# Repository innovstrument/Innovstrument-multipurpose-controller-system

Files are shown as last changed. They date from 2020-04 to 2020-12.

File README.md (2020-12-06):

# Innovstrument-multipurpose-controller-system

## 第一节 综述 Comprehensive Presentation

多用途控制系统，旨在提供一套除传统PLC解决方案之外，基于系统单芯片（SoC）平台的解决方案。它可以提供的软、硬件功能包括但不限于以下几点：

·实时的视频摄录和上传。

·基于网络、面向使用者的寻址/解析服务。该服务同时附带了基于LDAP的用户权限控制。

·

·

## 第二节 硬件部分 Hardware Section

### 主机板 Motherboard

基于Intel Apollo Lake平台，提供的扩展性能如下：

·显示：Display Port

·外设输出： 4* USB 3.0 

·网络：2* Intel i211

·

·

#### 待解决问题

·摄像头传感器：OmniVision OV5695 ，需要ASL CODE。

#### 第二版需要的更新

·剩余的4条PCIe通道从SFF-8612/8643口引出

·提供一个MIPI-DSI输出端子。

·板载存储从eMMC转换为microSD插槽

·显示接口变成mini DisplayPort或者使用USB Type-C连接器

·

### 背板/提升板 Backplane/Riser Board

#### 背板

预留4通道的PCI Express输入（SFF-8643/8612）

方案1：桥片使用PLX PEX8614 芯片，输出接口为SFF-8639。通道4，2，1，1.

方案2：桥片使用PLX PEX8608 芯片，输出接口为SFF-8639。通道1，1，1，1.

方案3：桥片使用PLX PEX8606 芯片，输入为两个PCIe通道。输出接口为SFF-8639，通道1，1，1，1.

#### 提升板

面积120* 120 毫米，输入为SFF-8643或8612接口，输出一个SFF-8639端口接U.2设备或者通过转接卡接M.2设备。

### 外接设备 Peripherals

目录：

1. 支持PoE的以太网卡

2. 以太网卡

3. 附属电池

4. 

### 模拟-数字信号转换控制模块 Analog-Digital Signal Convert and Control Module

·芯片 Analog Devices BF706: https://www.analog.com/cn/products/adsp-bf706.html#product-overview

·子通道控制 Analog Devices AD 5674：https://www.analog.com/media/en/technical-documentation/data-sheets/AD5674-5674R-5679-5679R.pdf

·提供的模拟输入：16路电压型 16路电流型

·提供的模拟输出：8路 10mA，0-5V.

·采样精度：10 bit.

图纸位于目录/master/Hardware/Analog-Digital%20Convert%20System下，编辑需要使用Altium Designer。

### 测试平台：

//

## 第三节 软件部分 Software Section

### 既有软件编程：可编程逻辑控制器程序 Existing Software Programming: PLC Program

Link: Programmable Logic System/Logic/消毒机(1).zap15_1

若需要编辑程序,需要西门子SIMATIC TIA 15.1 以上的版本访问

内网下载链接:(粤网 源创)

V 15.1: http://192.168.2.54/Software/Siemens/Simatic/0_TIA_Portal_v15.1_SitePack/

V 16.0: http://192.168.2.54/Software/Siemens/Simatic/TIA_Portal_V16/

## 第四节 其它注意事项 Misc.

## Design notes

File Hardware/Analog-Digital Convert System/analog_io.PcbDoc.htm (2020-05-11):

Reporting Options

# File in Previous Format

Date | : | 2020/5/8
Time | : | 16:24:50
Filename | : | C:\Users\chang\Downloads\analog_io\analog_io.PcbDoc

Version | Warning
Release 12 | CAUTION - Air Gap Width previously controlled by Clearance rule is now controlled by Polygon Connect Style rule's newly introduced Air Gap Width (set to default value). Suggest reviewing each Polygon Connect Style rule's Air Gap Width attribute for correctness.
Release 13 | CAUTION - Silkscreen Over Component Pads Rules are converted to Silk To Solder Mask Clearance Rules. Suggest examining rule scopes for accuracy.

This file was generated by an earlier version of the software

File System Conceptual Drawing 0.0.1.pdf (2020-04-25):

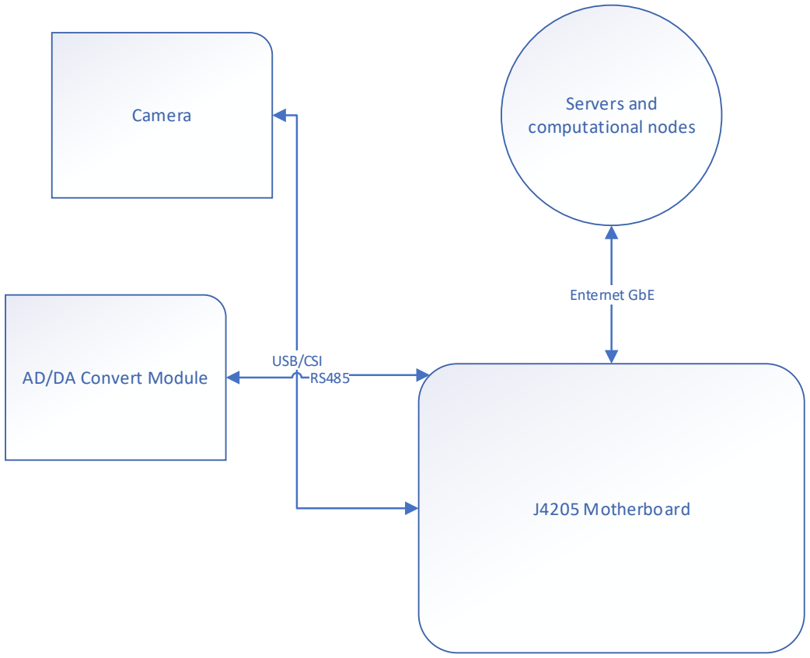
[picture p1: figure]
J4205 Motherboard; Servers and computational nodes; Enternet GbE; Camera; AD/DA Convert Module; USB/CSI RS485

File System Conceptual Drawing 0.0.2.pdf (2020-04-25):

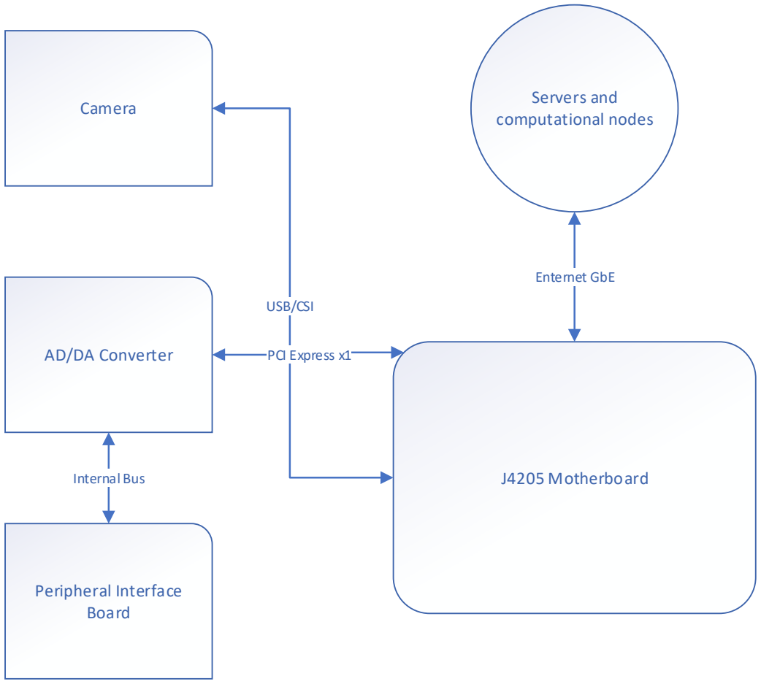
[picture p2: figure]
J4205 Motherboard; Servers and computational nodes; Enternet GbE; Camera; AD/DA Converter; USB/CSI; PCI Express x1; Peripheral Interface Board; Internal Bus

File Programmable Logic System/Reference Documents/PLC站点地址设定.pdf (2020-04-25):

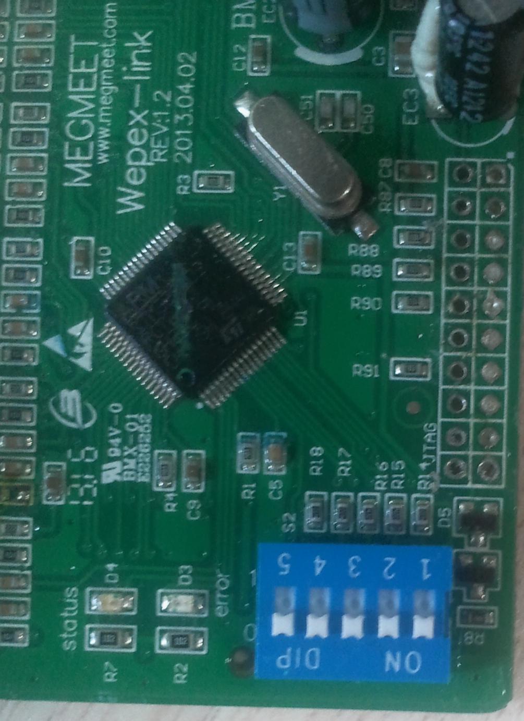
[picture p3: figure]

PLC 站点地址：1

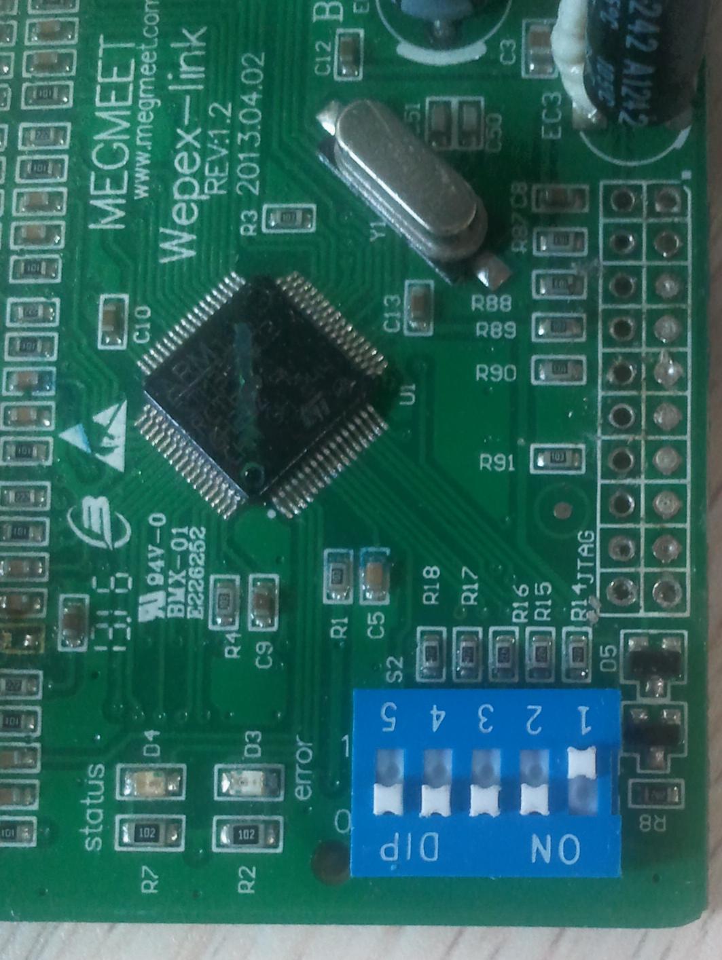
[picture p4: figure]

PLC 站点地址：2

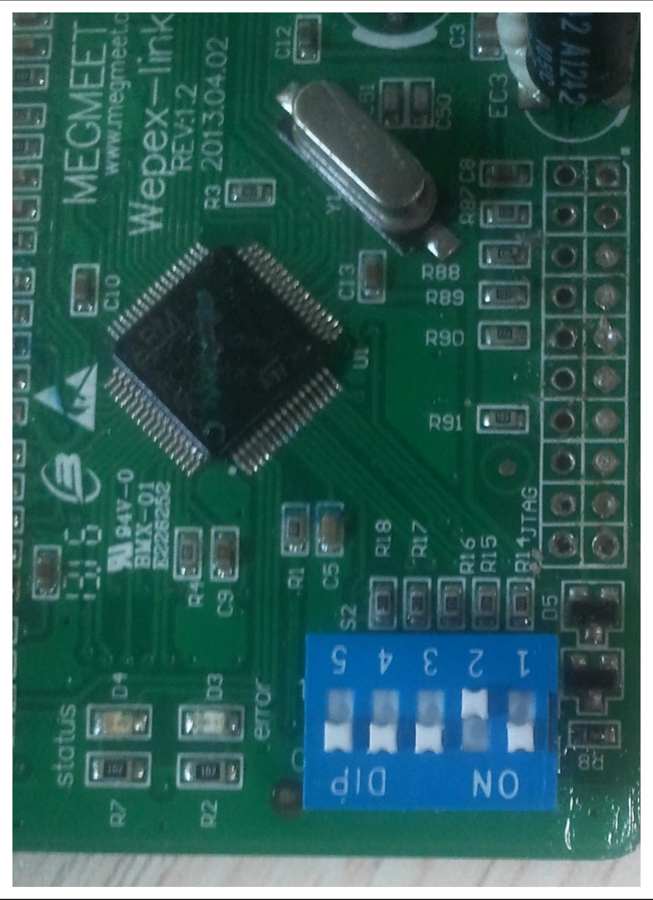
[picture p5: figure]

PLC 站点地址：3

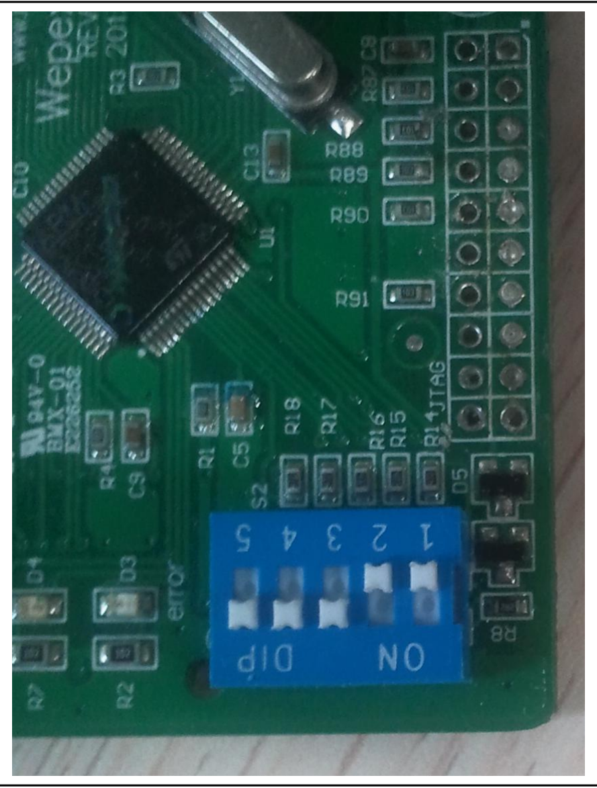
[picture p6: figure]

PLC 站点地址：4

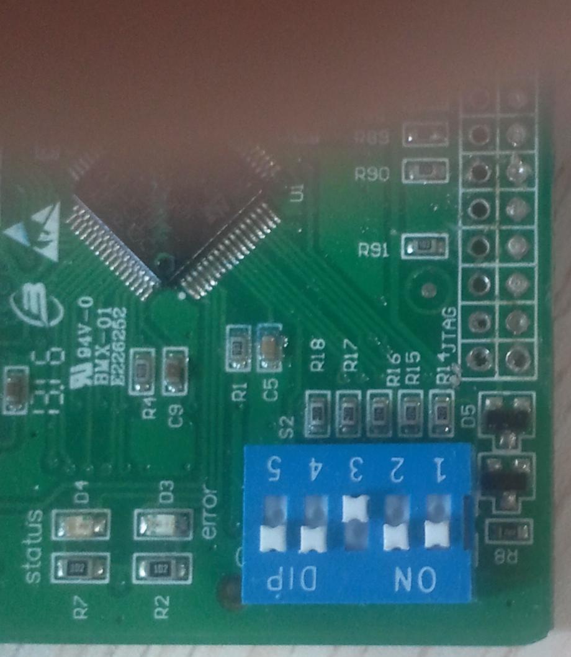
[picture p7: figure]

PLC 站点地址：5

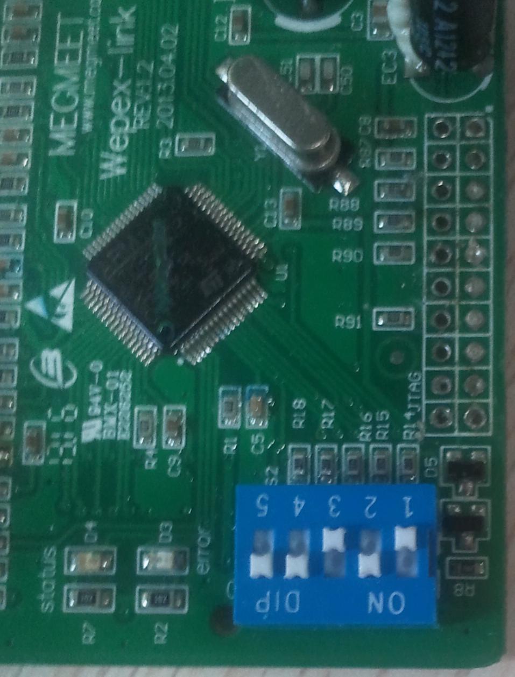
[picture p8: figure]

PLC 站点地址：6

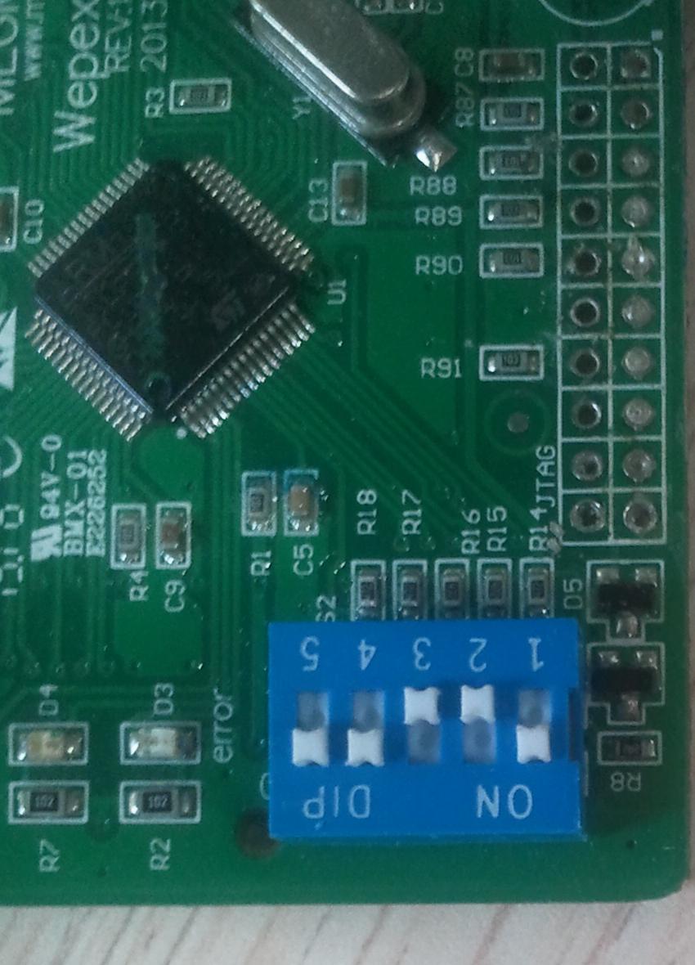
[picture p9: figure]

PLC 站点地址：7

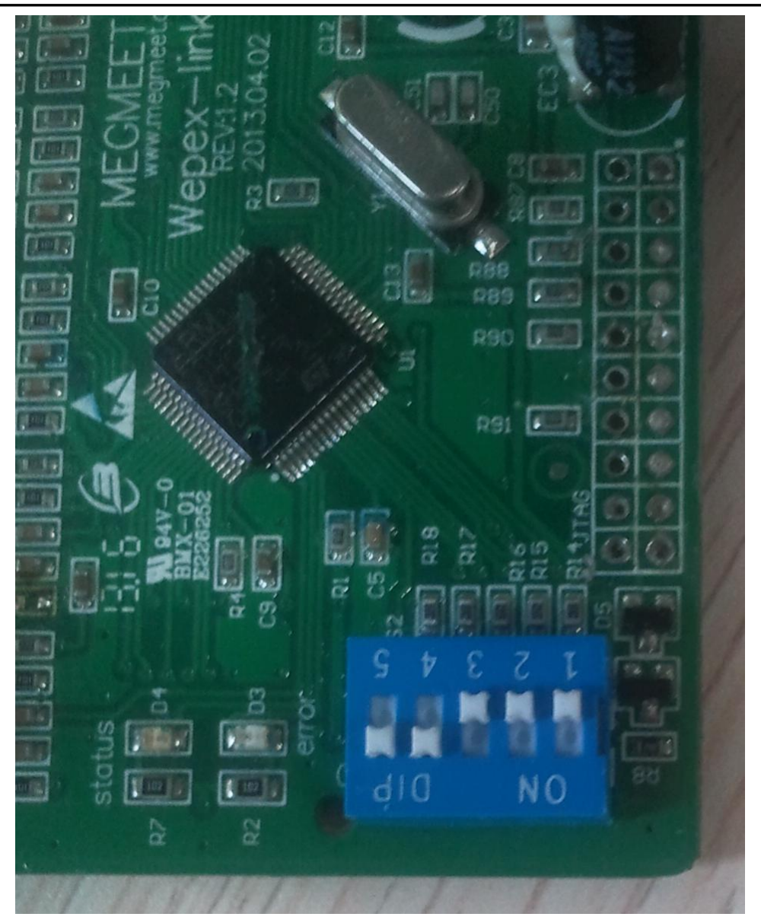
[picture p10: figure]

PLC 站点地址：8

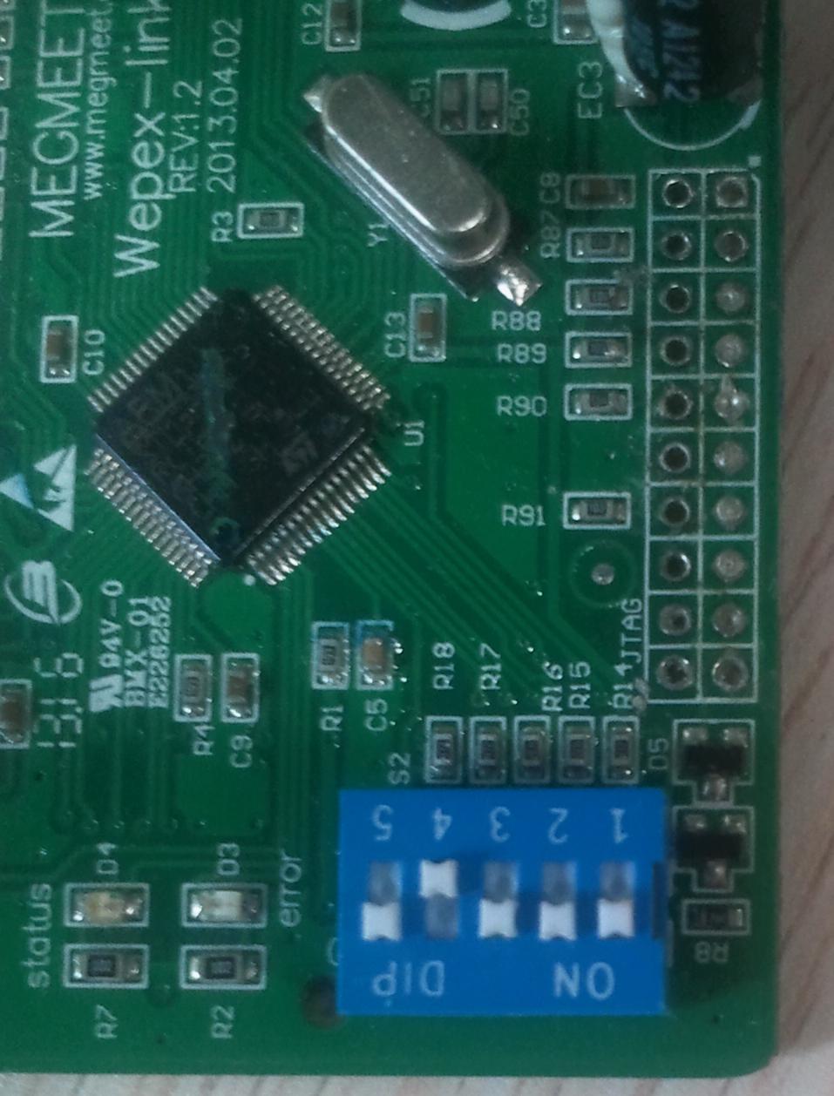
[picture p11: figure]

PLC 站点地址：9

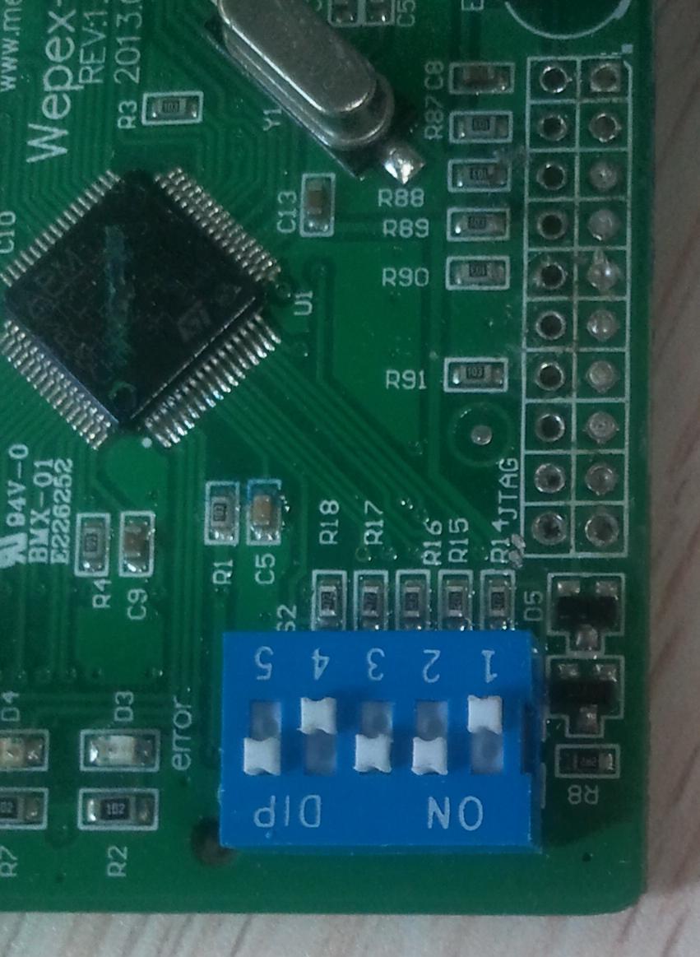
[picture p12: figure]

## PLC 站点地址：10

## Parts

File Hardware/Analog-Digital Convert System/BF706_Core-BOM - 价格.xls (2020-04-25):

Comment | Description | Designator | Footprint | LibRef | Quantity | 单价 | 总价
 | Tant Cap | C100, C101, C104, C105 | C1206T | Cap Pol2 | 4 |  | 0 | 电容的容量大小是多少？
2.2uF | Capacitor | C102, C103 | C0603 | Cap | 2 | 0.11 | 0.22
100nF | Capacitor | C106, C107, C108, C109, C110, C111, C112, C113, C114, C115, C116, C117, C118, C119, C120, C300 | C0603 | Cap | 16 | 0.043 | 0.688
18pF | Capacitor | C200, C201 | C0603 | Cap | 2 | 0.11 | 0.22
MINI-PCIE(DNP) |  | CN | PCI-E MALE | MINI-PCIE | 1 |  | 0
LED GREEN | LED GREEN | D100 | LED0603 | LED0 | 1 | 0.097 | 0.097
LED RED | LED RED | D200 | LED0603 | LED0 | 1 | 0.097 | 0.097
0512811094 | Header, 10-Pin | JTAG | MOLEX-FPC-0.5-10 | Header 10 | 1 | 0.49 | 0.49
SRN3015-2R2M | Resistor | L100, L101 | SRN3015 | Res1 | 2 | 3.59 | 7.18
10k | Resistor | R100, R200, R202, R205, R207, R208, R209, R210, R300, R301, R302, R303, R304 | R0603 | Res1 | 13 | 0.022 | 0.286
12k | Resistor | R101, R104 | R0603 | Res1 | 2 | 0.019 | 0.038
1k |  | R102 | R0603 | Res1 | 1 | 0.028 | 0.028
53.6k | Resistor | R103 | R0603 | Res1 | 1 | 0.011 | 0.011
330 |  | R201 | R0603 | Res1 | 1 | 0.02 | 0.02
DNP | Resistor | R203, R204 | R0603 | Res1 | 2 |  | 0
0R | Resistor | R206 | R0603 | Res1 | 1 | 0.009 | 0.009
ADSP-BF706BCPZ-4 |  | U100 | ADSP-BF706 | ADSP-BF706 | 1 | 137.4 | 137.4
RT8059 |  | U101, U102 | APS1006 | RT8059 | 2 | 0.67 | 1.34
ASE-24.000MHZ-LC-T | 24MHz XTAL OSC | U200 | XTAL-25M-SMD | XTAL-25M | 1 | 12.5 | 12.5
MAX811TEUS+T |  | U201 | sot143 | MAX811 | 1 | 18.4 | 18.4
W25Q32JVSSIQ |  | U300 | M25P80 | M25P16 | 1 | 2.22 | 2.22
ABM3C-25.000MHZ-D4Y-T | 25MHz XTAL | X200 | XTAL5032 | XTAL-25M-SMD | 1 | 6.15 | 6.15
 |  |  |  |  |  |  | 187.394

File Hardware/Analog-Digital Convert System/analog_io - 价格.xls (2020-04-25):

Comment | Description | Designator | Footprint | LibRef | Quantity | 单价 | 总价
1uF | Capacitor | C1, C2, C3, C5, C7, C9, C25, C26, C27, C28, C29, C30, C31, C32, C33, C34, C35, C36, C37, C38, C39, C40 | C0603 | Cap | 22 | 0.063 | 1.386
100nF | GRM155R71C104KA88J | C4, C6, C8, C10, C12, C14, C16, C18, C44, C46 | C0603 | Cap | 10 | 0.043 | 0.43
10uF | Capacitor | C11, C13, C15, C17, C45 | C1206N | Cap | 5 | 0.25 | 1.25
4.7uF | Capacitor | C19, C21, C22, C24, C41, C43 | TANT_B | Cap | 6 |  | 0 | 封装不清楚，是钽电容吗？具体封装是什么？
4.7uF | Capacitor | C20, C23, C42 | C0603 | Cap | 3 | 0.25 | 0.75
Phoenix Contact 1843156 | Header, 10-Pin, Dual row | CN1, CN2, CN3 | PHOENIX1843156 | Header 10X2 | 3 | 99 | 297
Header 24 | Header, 24-Pin | CN300 | FPC-0.5-24 | Header 24 | 1 | 0.58 | 0.58
LED0 | Typical INFRARED GaAs LED | D1, D2, D3 | LED0603 | LED0 | 3 | 0.097 | 0.291
10R | Resistor | R1, R2, R3, R4, R5, R6, R7, R8, R9, R10, R11, R12, R13, R14, R15, R16 | R0603 | Res1 | 16 | 0.017 | 0.272
2.2k | Resistor | R17, R18, R23 | R0603 | Res1 | 3 | 0.015 | 0.045
YC164-33R |  | R19, R22 | YC164 | YC164 | 2 | 0.07 | 0.14
33R | Resistor | R20, R21 | R0603 | Res1 | 2 | 0.037 | 0.074
SMAJ10CA |  | TVS1, TVS2, TVS3, TVS4, TVS5, TVS6, TVS7, TVS8, TVS9, TVS10, TVS11, TVS12, TVS13, TVS14, TVS15, TVS16 | SMA | DIODE | 16 | 0.34 | 5.44
AD4111 |  | U1, U2 | AD7119 | AD4111 | 2 | 118.4 | 236.8
AMS1117 |  | U6 | SOT223 | AMS1117-5V | 1 | 0.7 | 0.7
AMS1117 |  | U3, U4 | SOT223 | AMS1117-3.3V | 2 | 0.7 | 1.4
AD5674 |  | U5 | PNI-MAGI2C | AD5674 | 1 | 140 | 140
 |  |  |  |  |  |  | 686.558

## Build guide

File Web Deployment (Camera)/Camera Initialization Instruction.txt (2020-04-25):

Environment initialization Test:
# Set 
# List Camera Devices
ffmpeg -list_devices true -f dshow -i dummy
ffplay -f dshow -i video="Integrated Webcam" out2.mp4
# Activate HLS Steaming
ffmpeg -y -rtbufsize 1024M -f dshow -i video="Integrated Webcam" -vcodec libx264 ¨Cthreads 2 -f hls -hls_list_size 0 -hls_wrap 10 -hls_time 10 "C:\Web Deployment\wwwroot\Webcam\Buffer\Cam01\C1.m3u8"

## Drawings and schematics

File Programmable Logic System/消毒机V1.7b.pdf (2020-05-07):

| | | | 2020/3/13 | ‎深圳粤网节能技术服务有限公司 ‎消毒机控制系统 | ‎广州洁科不锈钢设备 ‎有限公司 | ‎封页 | = COVER
| | | ‎校对 | ADMIN | | | | +
| | | ‎审核 | | | | | GB_tpl001 | ‎页数
‎修改 | ‎日期 | ‎姓名 | ‎原始项目 | | ‎替换 | ‎替换人 | | | | ‎页
0 | 6 | 7
3 | 8 | 9

## =SCH+P7_PLC/1

# ‎深圳粤网节能技术服务有限公司

# ‎消毒机控制系统电气原理图

# ‎工程编号XXX-YYY-ZZZ

# ‎______年___月

# ‎施工图

X1

X1

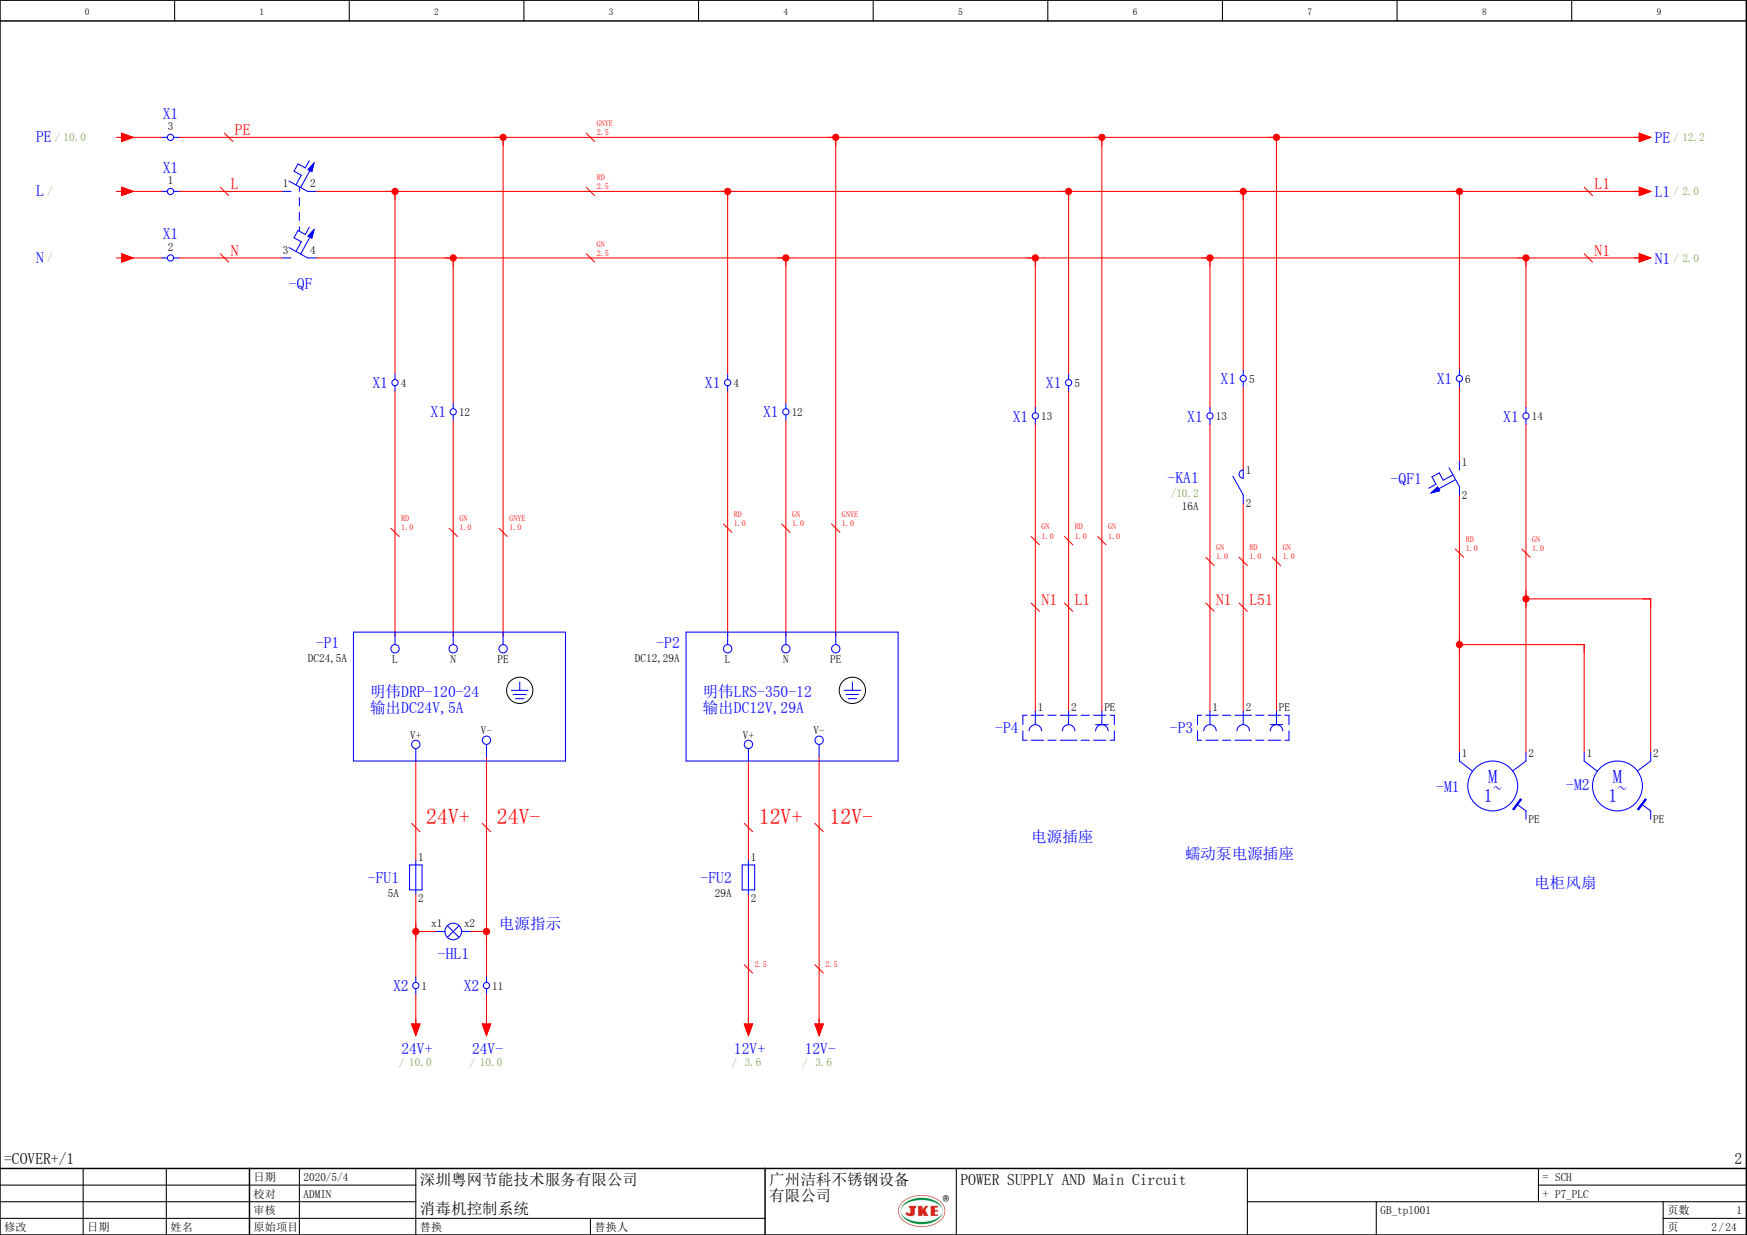
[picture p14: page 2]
=COVER+/1; SCH; P7_PLC; ‎广州洁科不锈钢设备; ‎电柜风扇; ‎明伟DRP-120-24 ‎输出DC24V,5A; ‎电源指示; ‎蠕动泵电源插座; ‎电源插座; ‎明伟LRS-350-12 ‎输出DC12V,29A; GNYE

POWER SUPPLY AND Main Circuit

24V+

-KM1

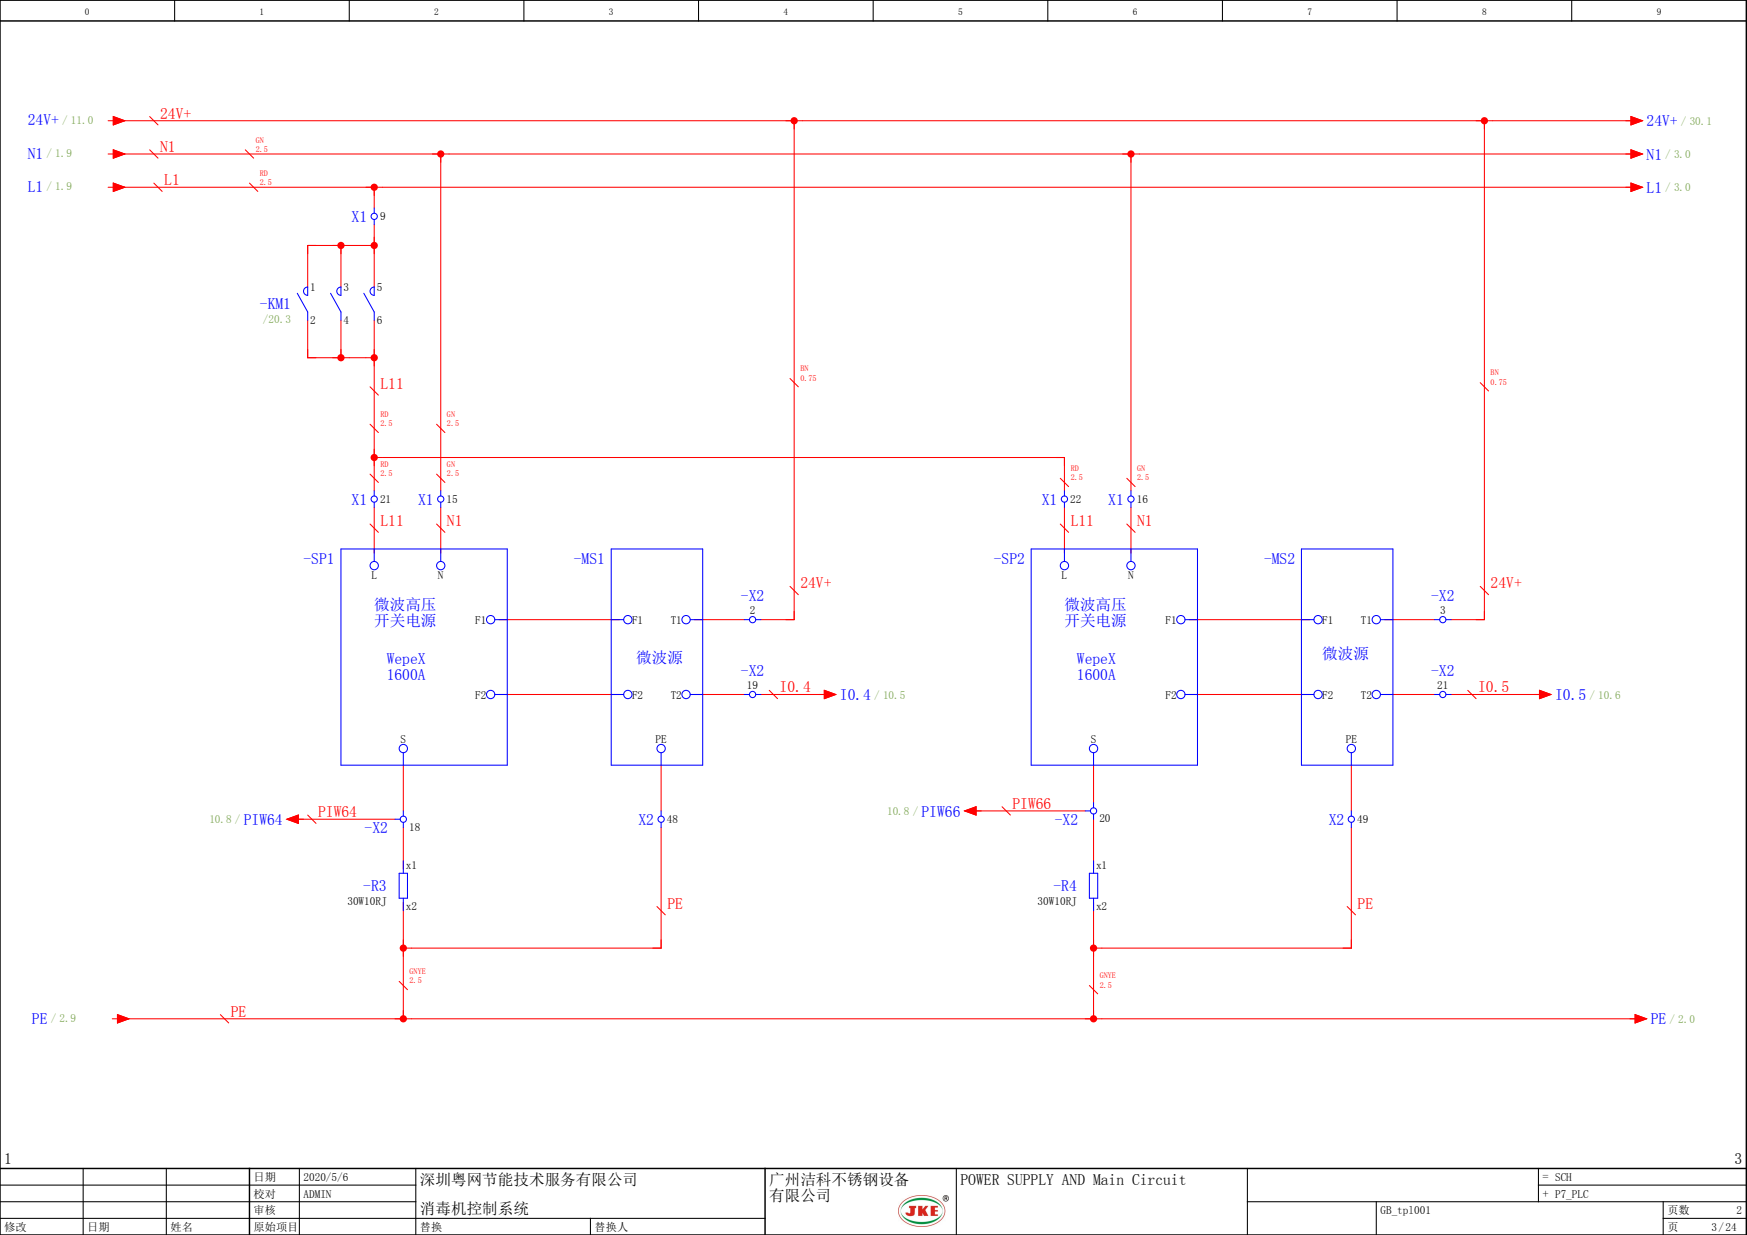
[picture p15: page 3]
SCH; P7_PLC; ‎广州洁科不锈钢设备; WepeX 1600A; ‎微波高压 ‎开关电源; ‎微波源; PIW66 PIW64; GNYE; 10.8 / PIW64; 10.8 / PIW66

POWER SUPPLY AND Main Circuit

L1

N1

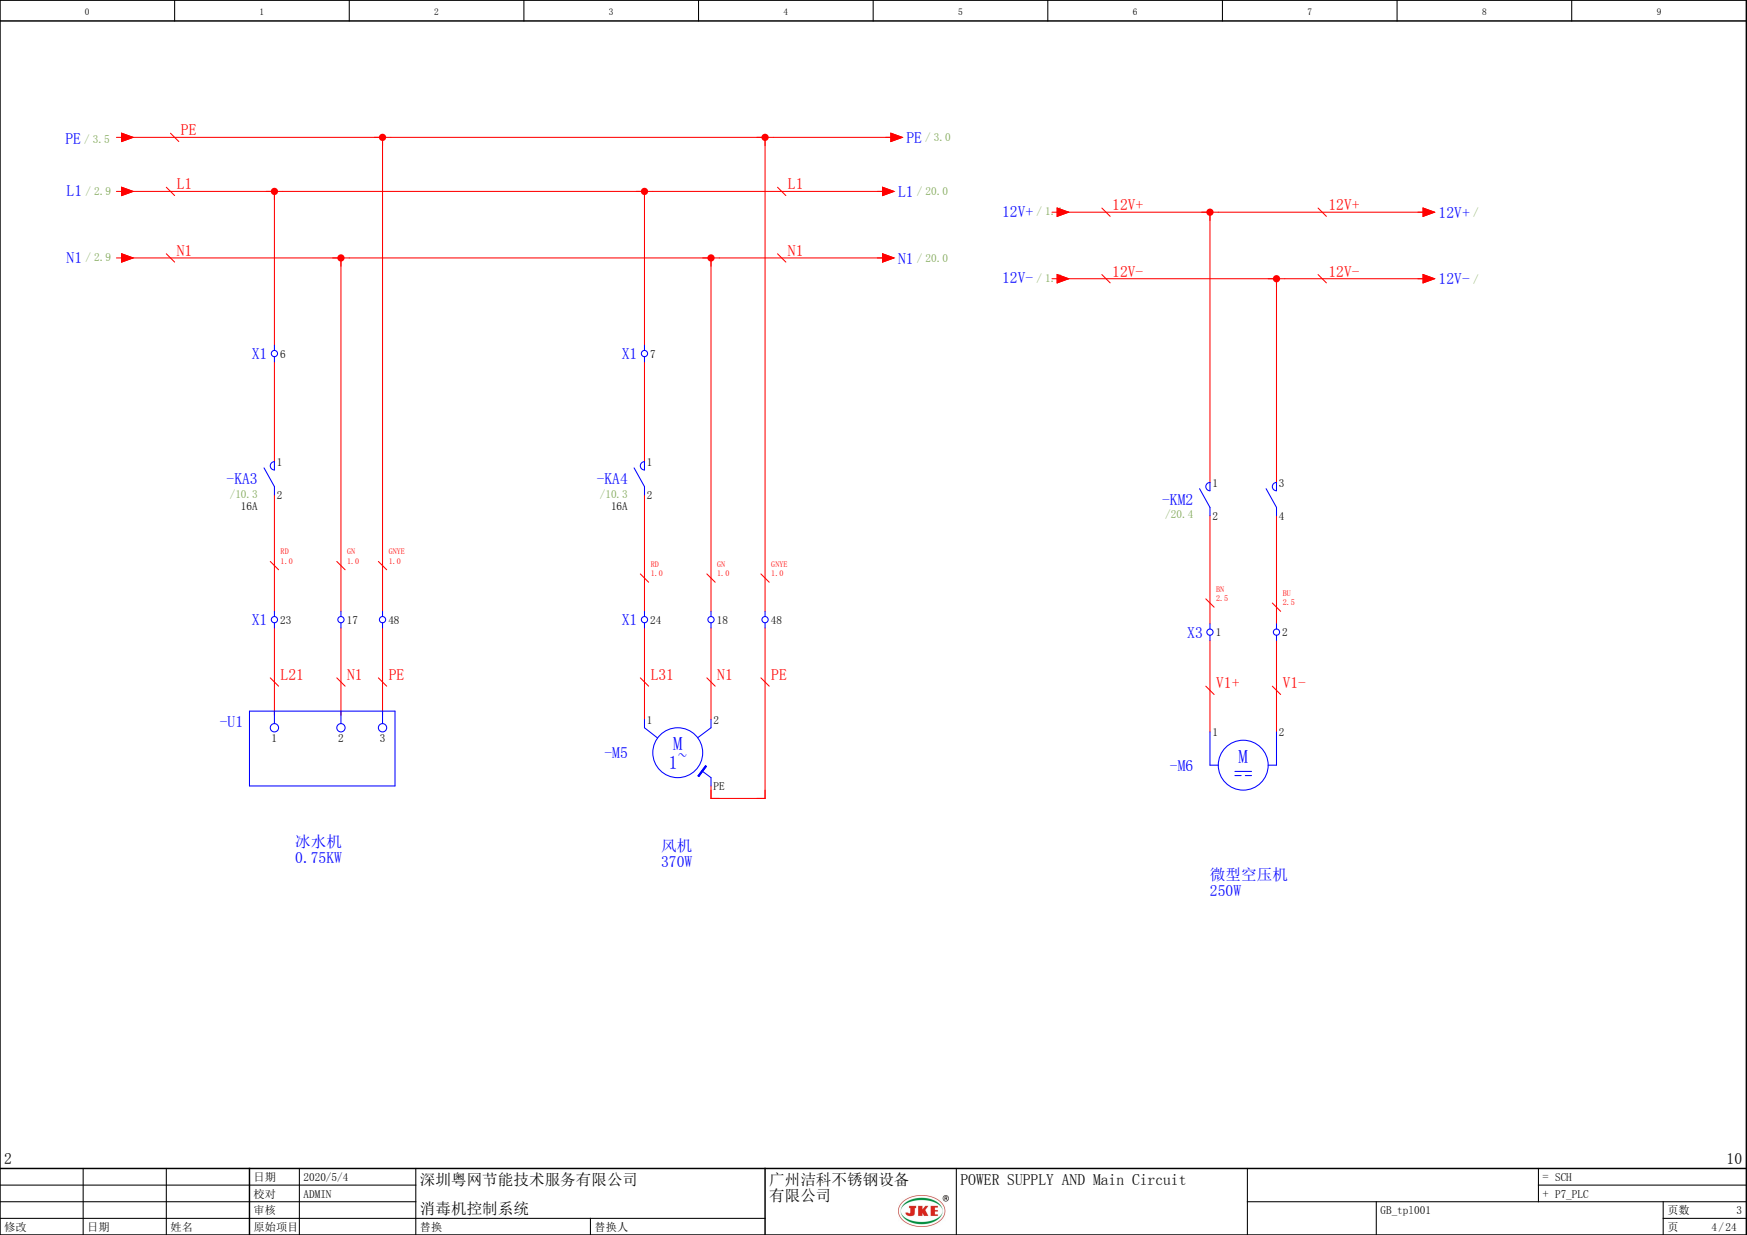
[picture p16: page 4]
SCH; P7_PLC; ‎广州洁科不锈钢设备; ‎冰水机 0.75KW; ‎微型空压机 250W; GNYE

POWER SUPPLY AND Main Circuit

24V+

24V-

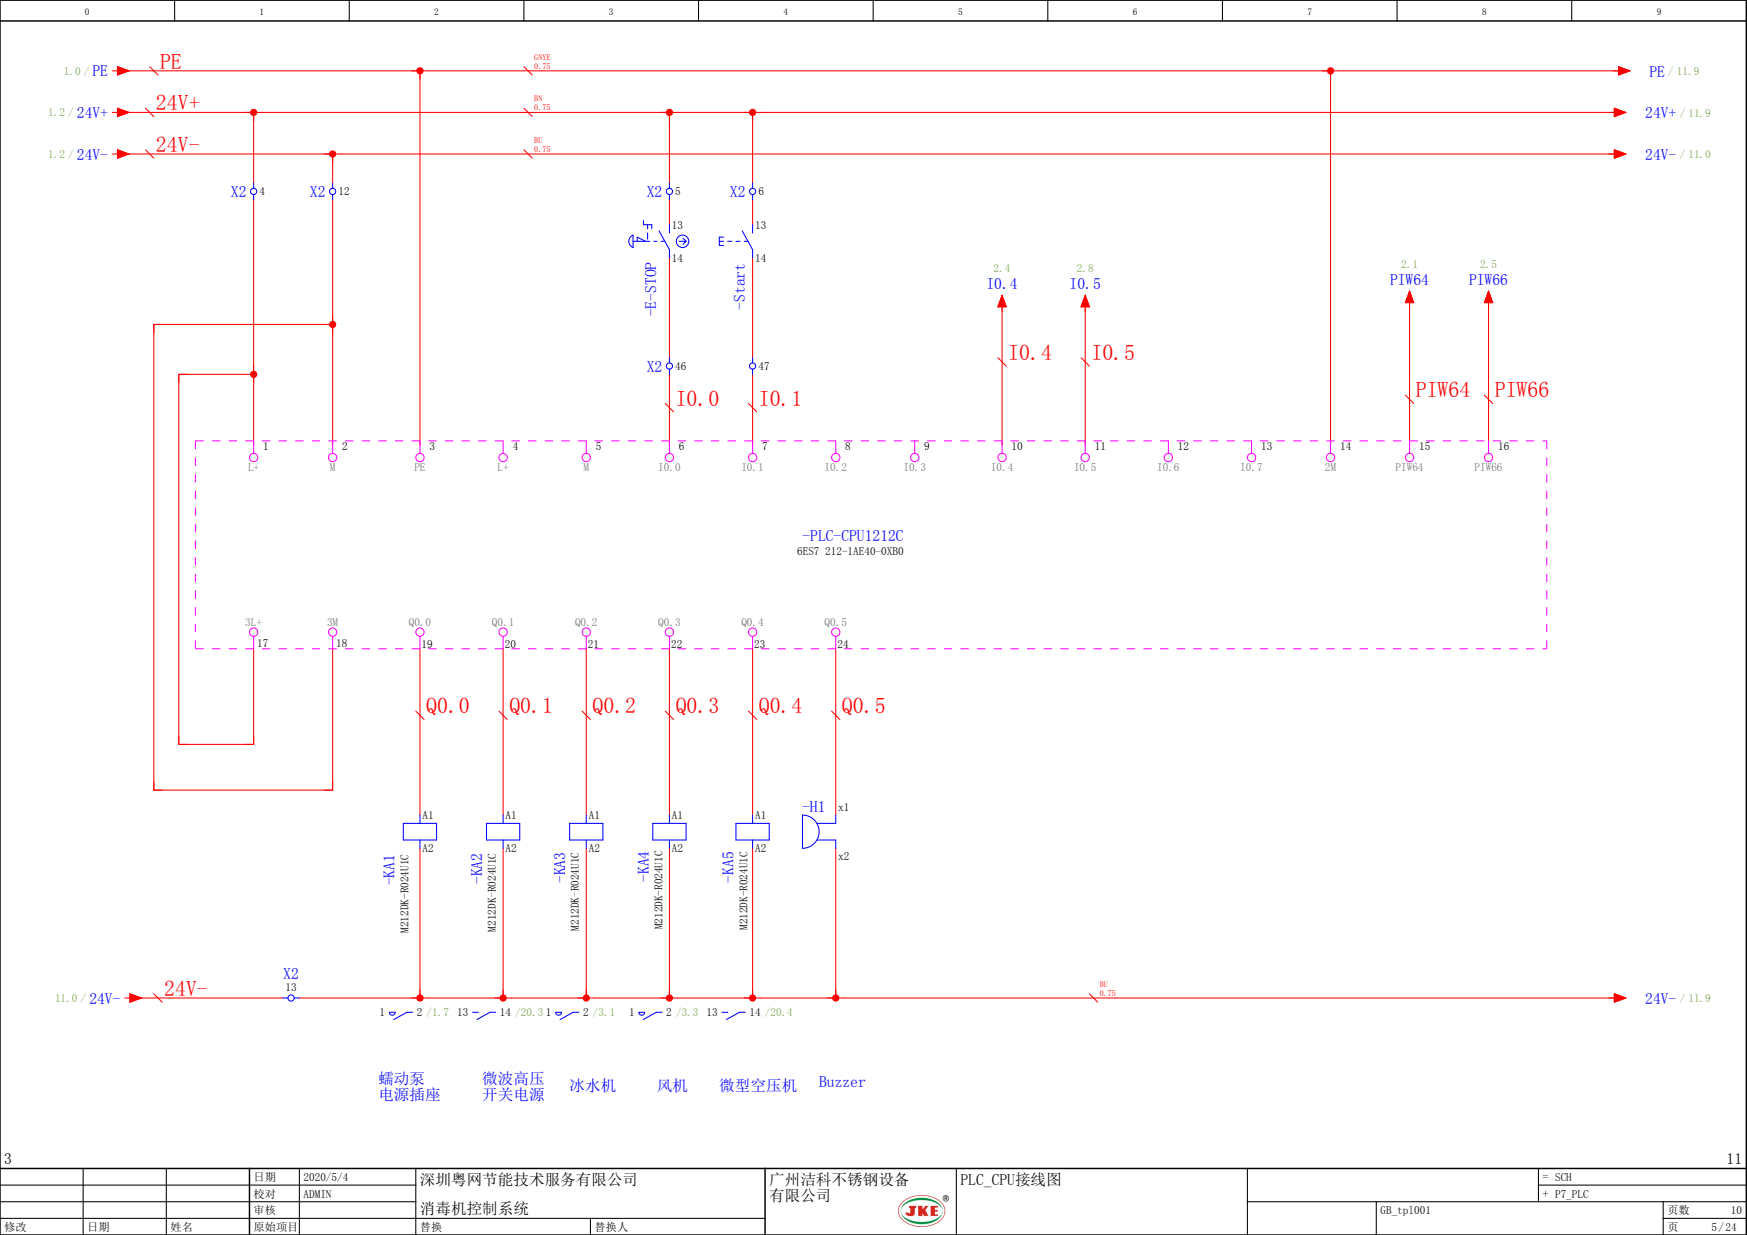
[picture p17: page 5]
SCH; P7_PLC; ‎PLC_CPU接线图; ‎广州洁科不锈钢设备; ‎蠕动泵 ‎电源插座; ‎微波高压; ‎开关电源; ‎冰水机; ‎微型空压机; Buzzer; -PLC-CPU1212C; PIW64; PIW66; -E-STOP; -Start; GNYE

24V+

24V-

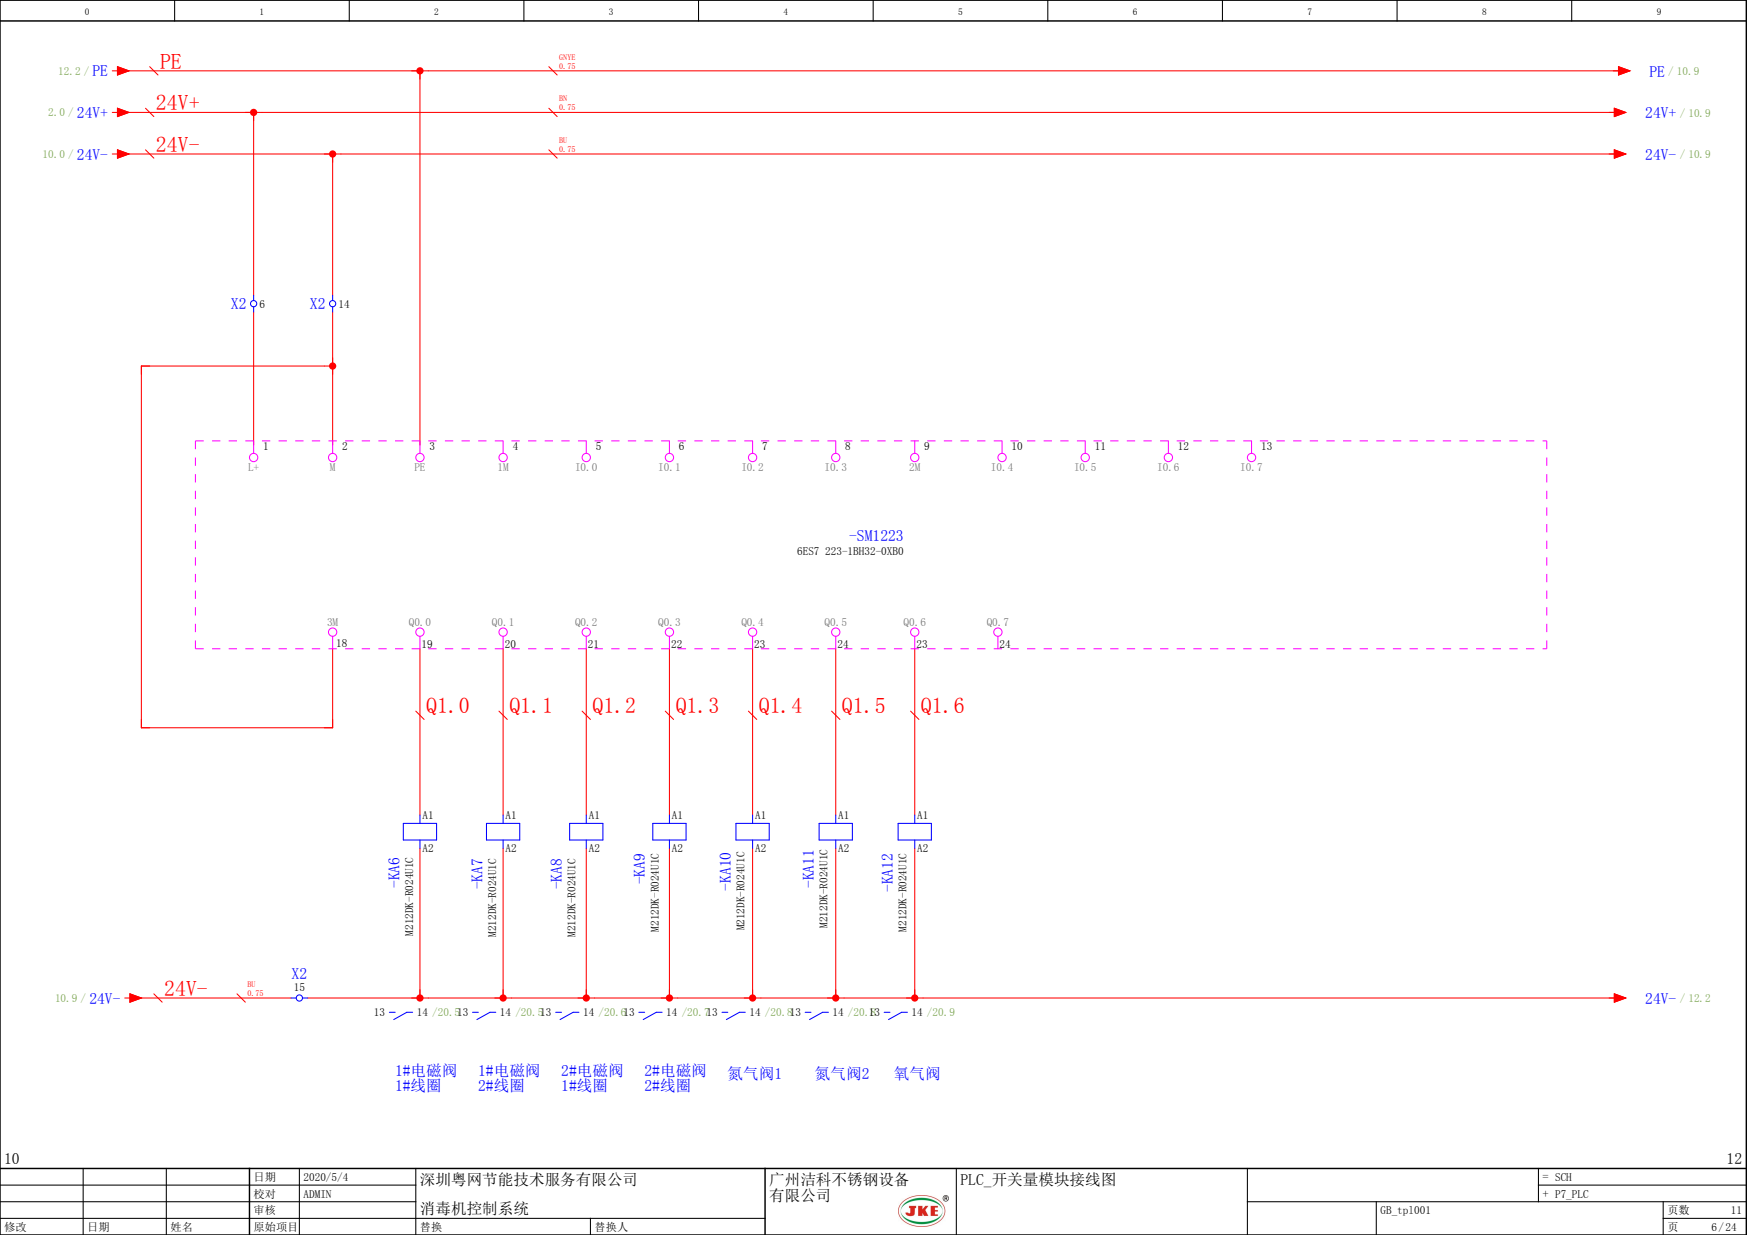
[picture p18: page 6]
SCH; P7_PLC; ‎PLC_开关量模块接线图; ‎广州洁科不锈钢设备; ‎1#电磁阀 ‎1#线圈; ‎1#电磁阀 ‎2#线圈; ‎2#电磁阀 ‎1#线圈; ‎2#电磁阀; ‎氮气阀1; ‎氮气阀2; ‎氧气阀; GNYE

24V+

24V-

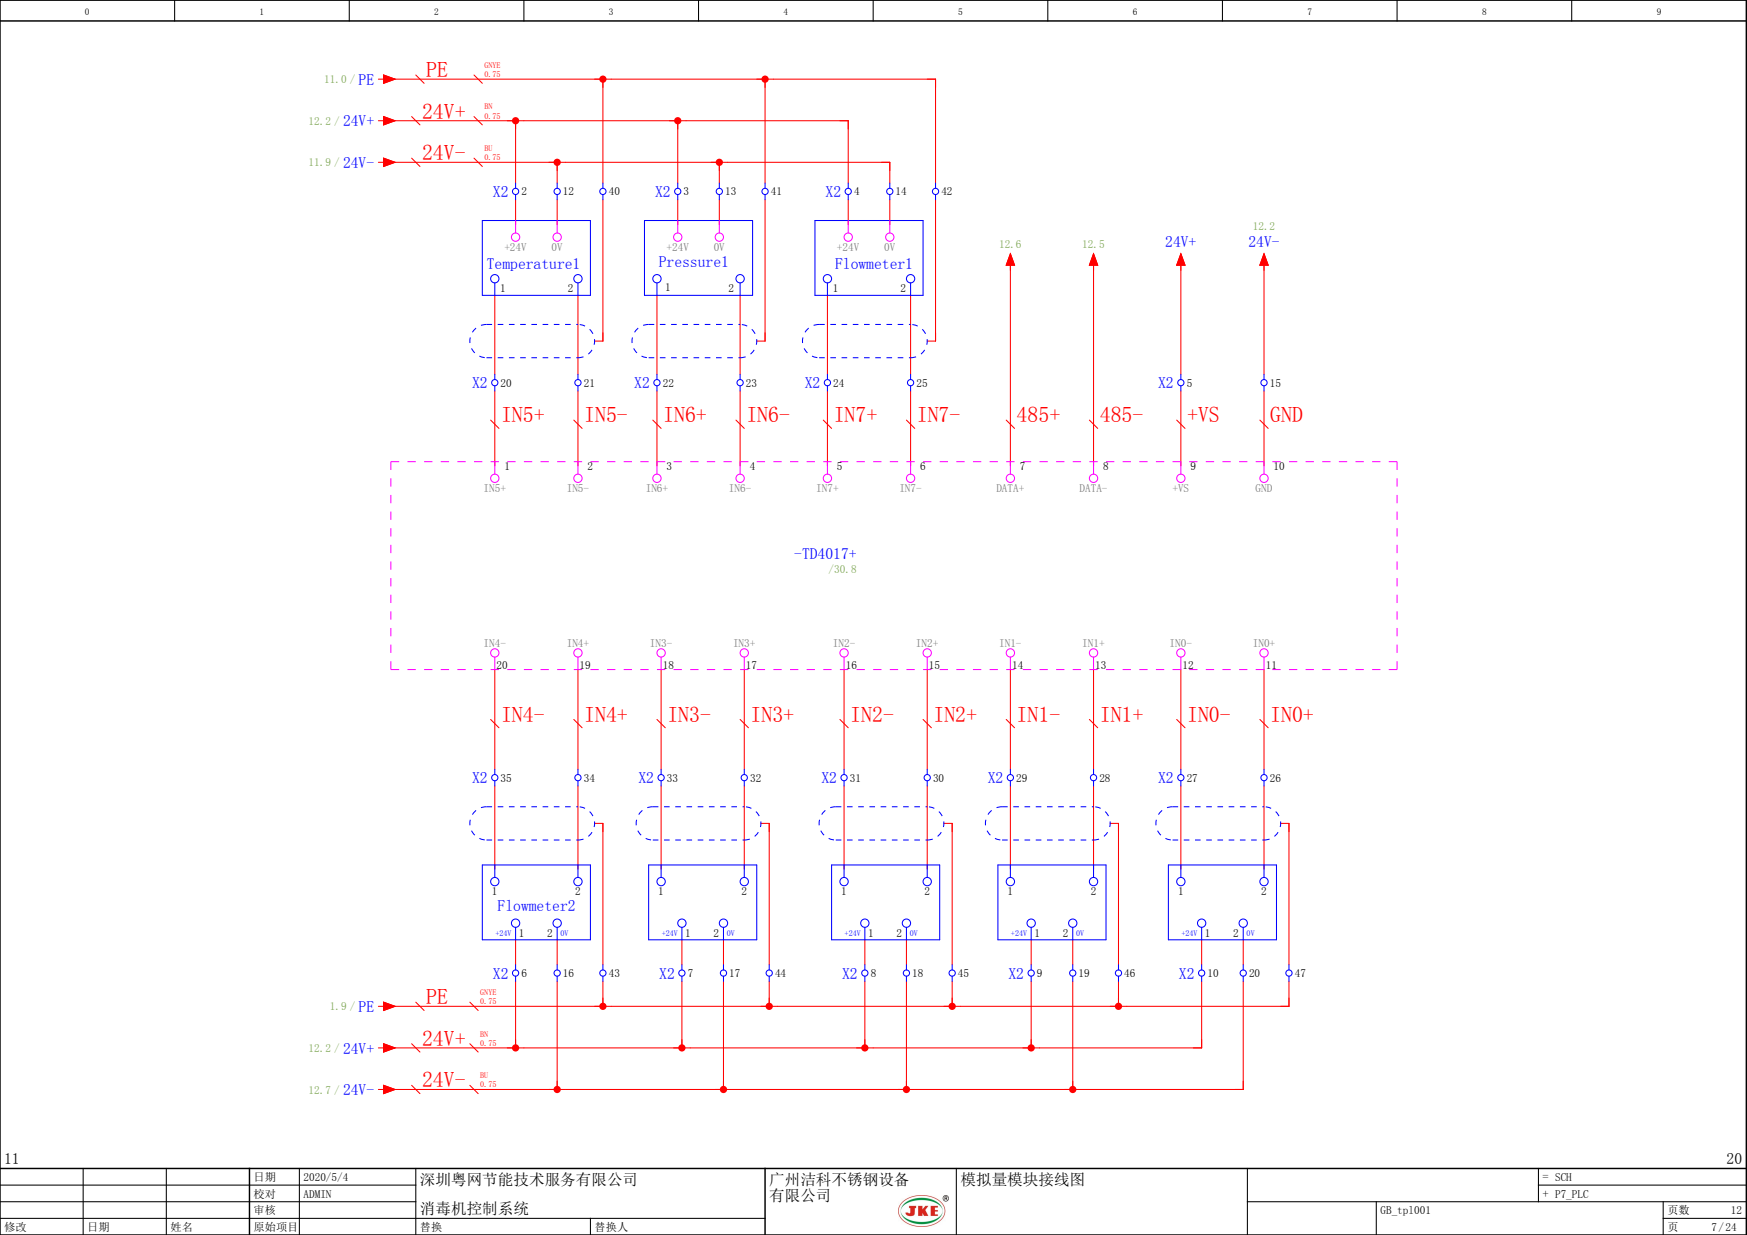
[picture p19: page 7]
SCH; P7_PLC; ‎模拟量模块接线图; ‎广州洁科不锈钢设备; Temperature1; Pressure1; Flowmeter2; Flowmeter1; DATA+; DATA-; GND; GNYE

L1

X1

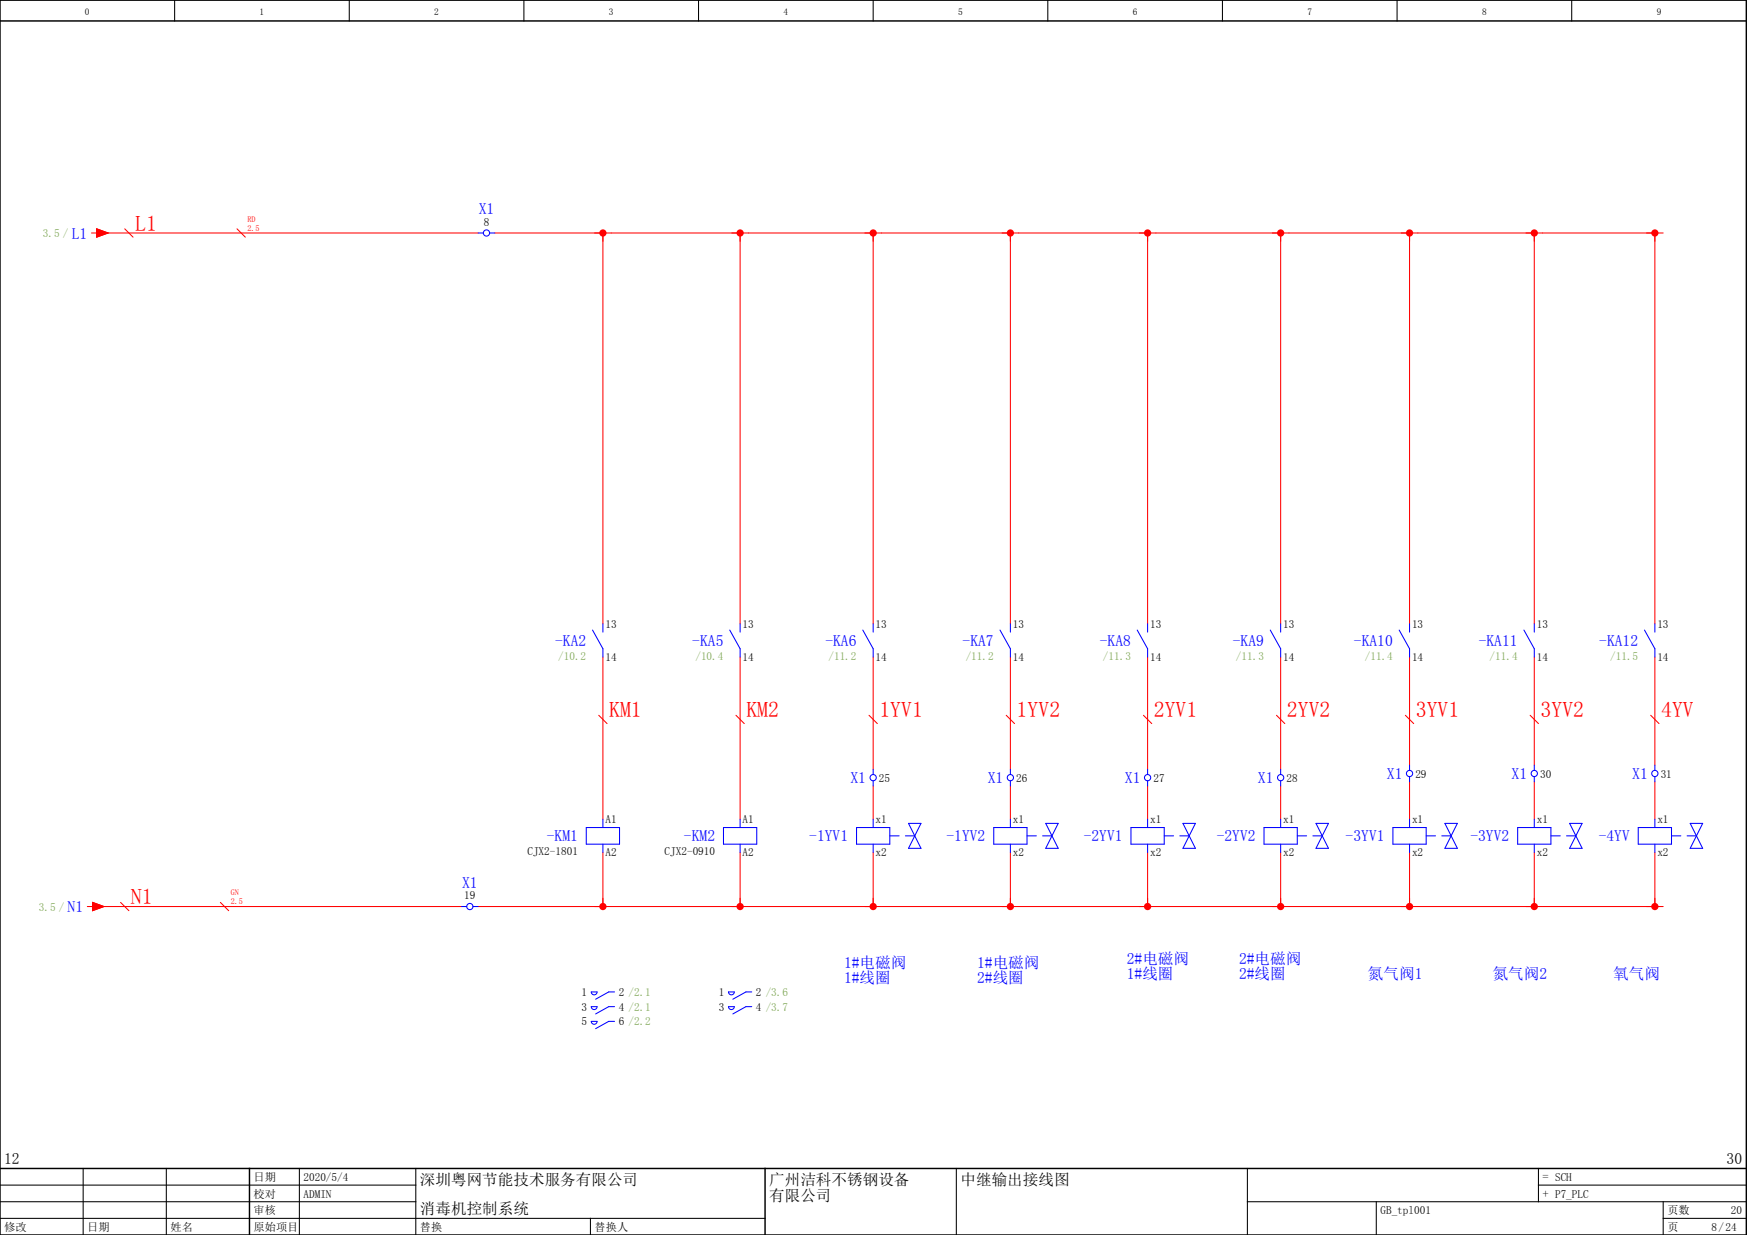
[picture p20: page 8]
SCH; P7_PLC; ‎中继输出接线图; ‎广州洁科不锈钢设备; ‎1#电磁阀 ‎1#线圈; ‎1#电磁阀 ‎2#线圈; ‎2#电磁阀 ‎1#线圈; ‎2#电磁阀; ‎氮气阀1; ‎氮气阀2; ‎氧气阀; CJX2-1801; CJX2-0910

24V+

24V-

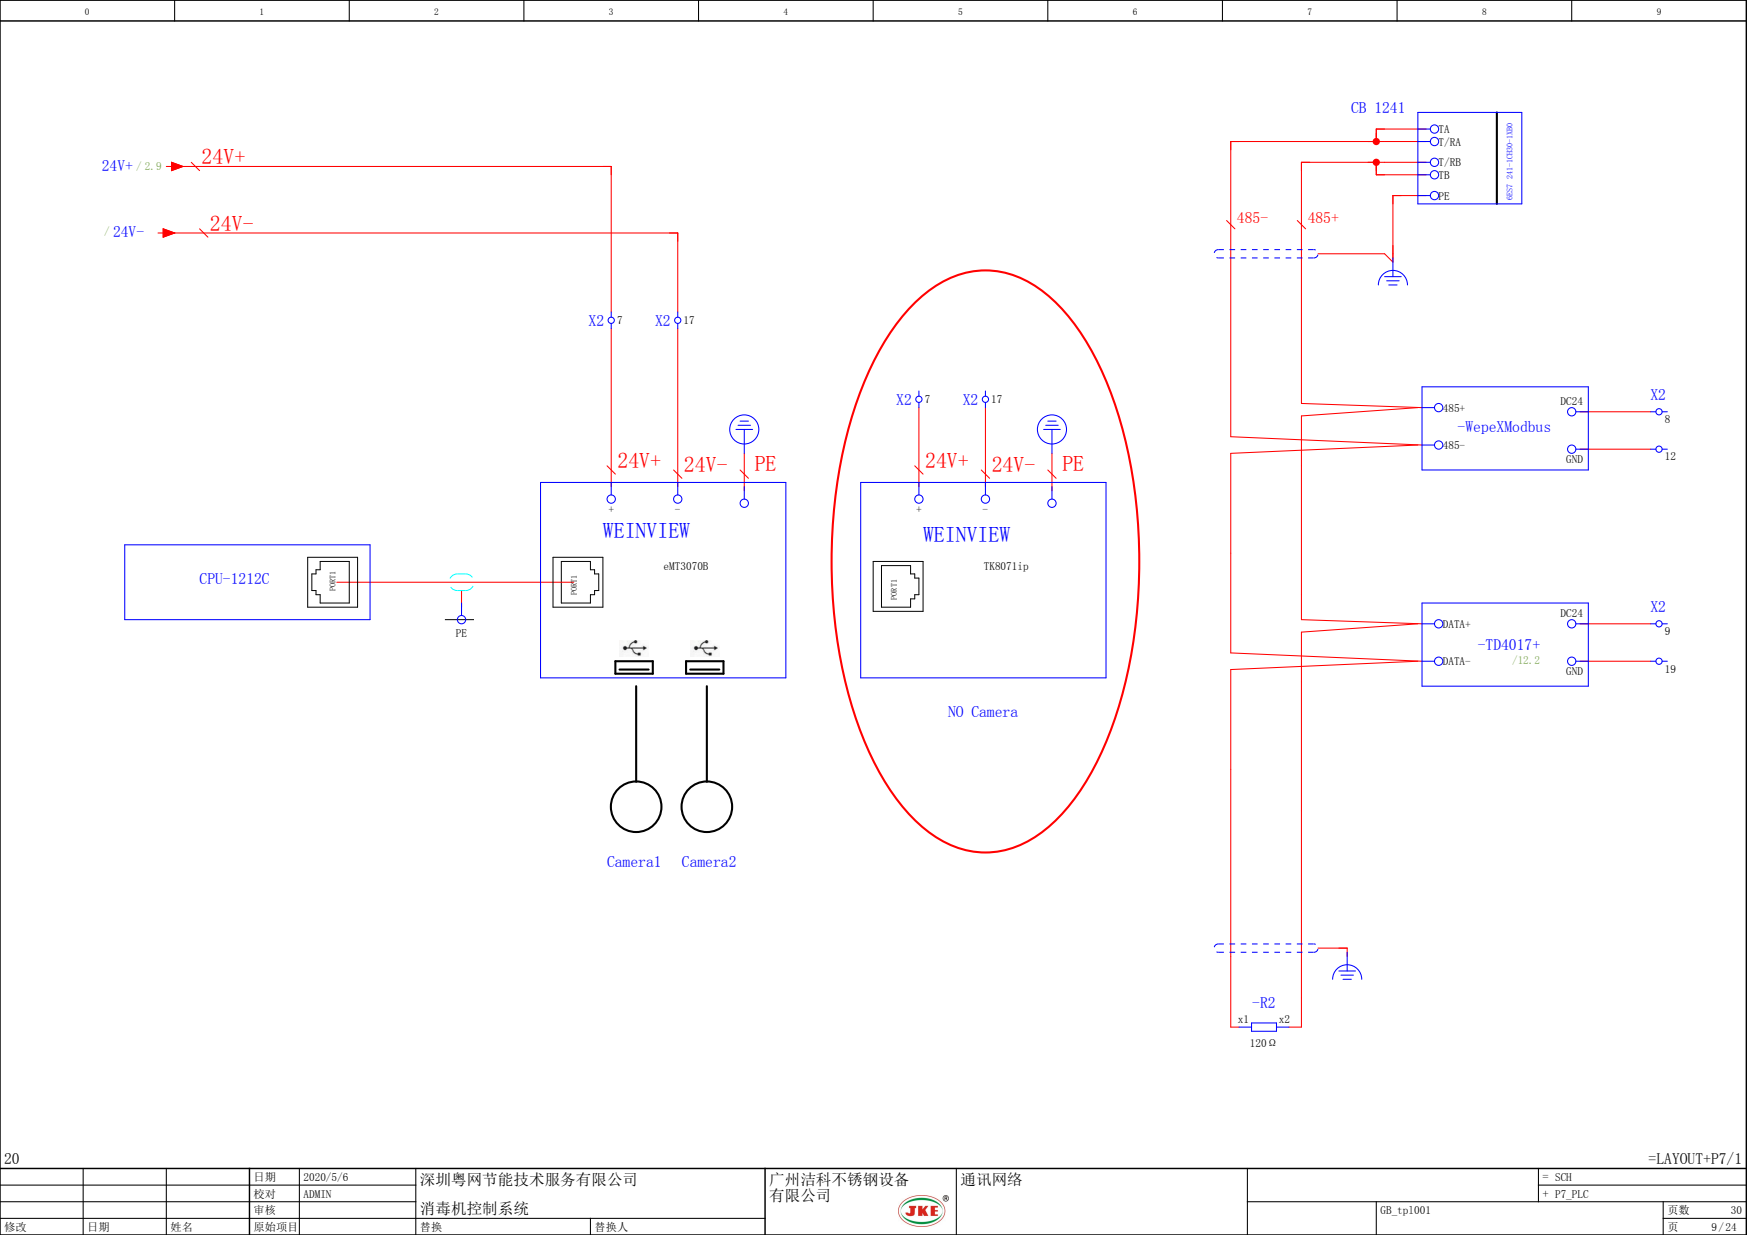
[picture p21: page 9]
SCH; P7_PLC; ‎通讯网络; =LAYOUT+P7/1; ‎广州洁科不锈钢设备; CPU-1212C; WEINVIEW; Camera1; Camera2; NO Camera; -WepeXModbus; PORT1; eMT3070B; DATA+; DATA-; GND

500 mm

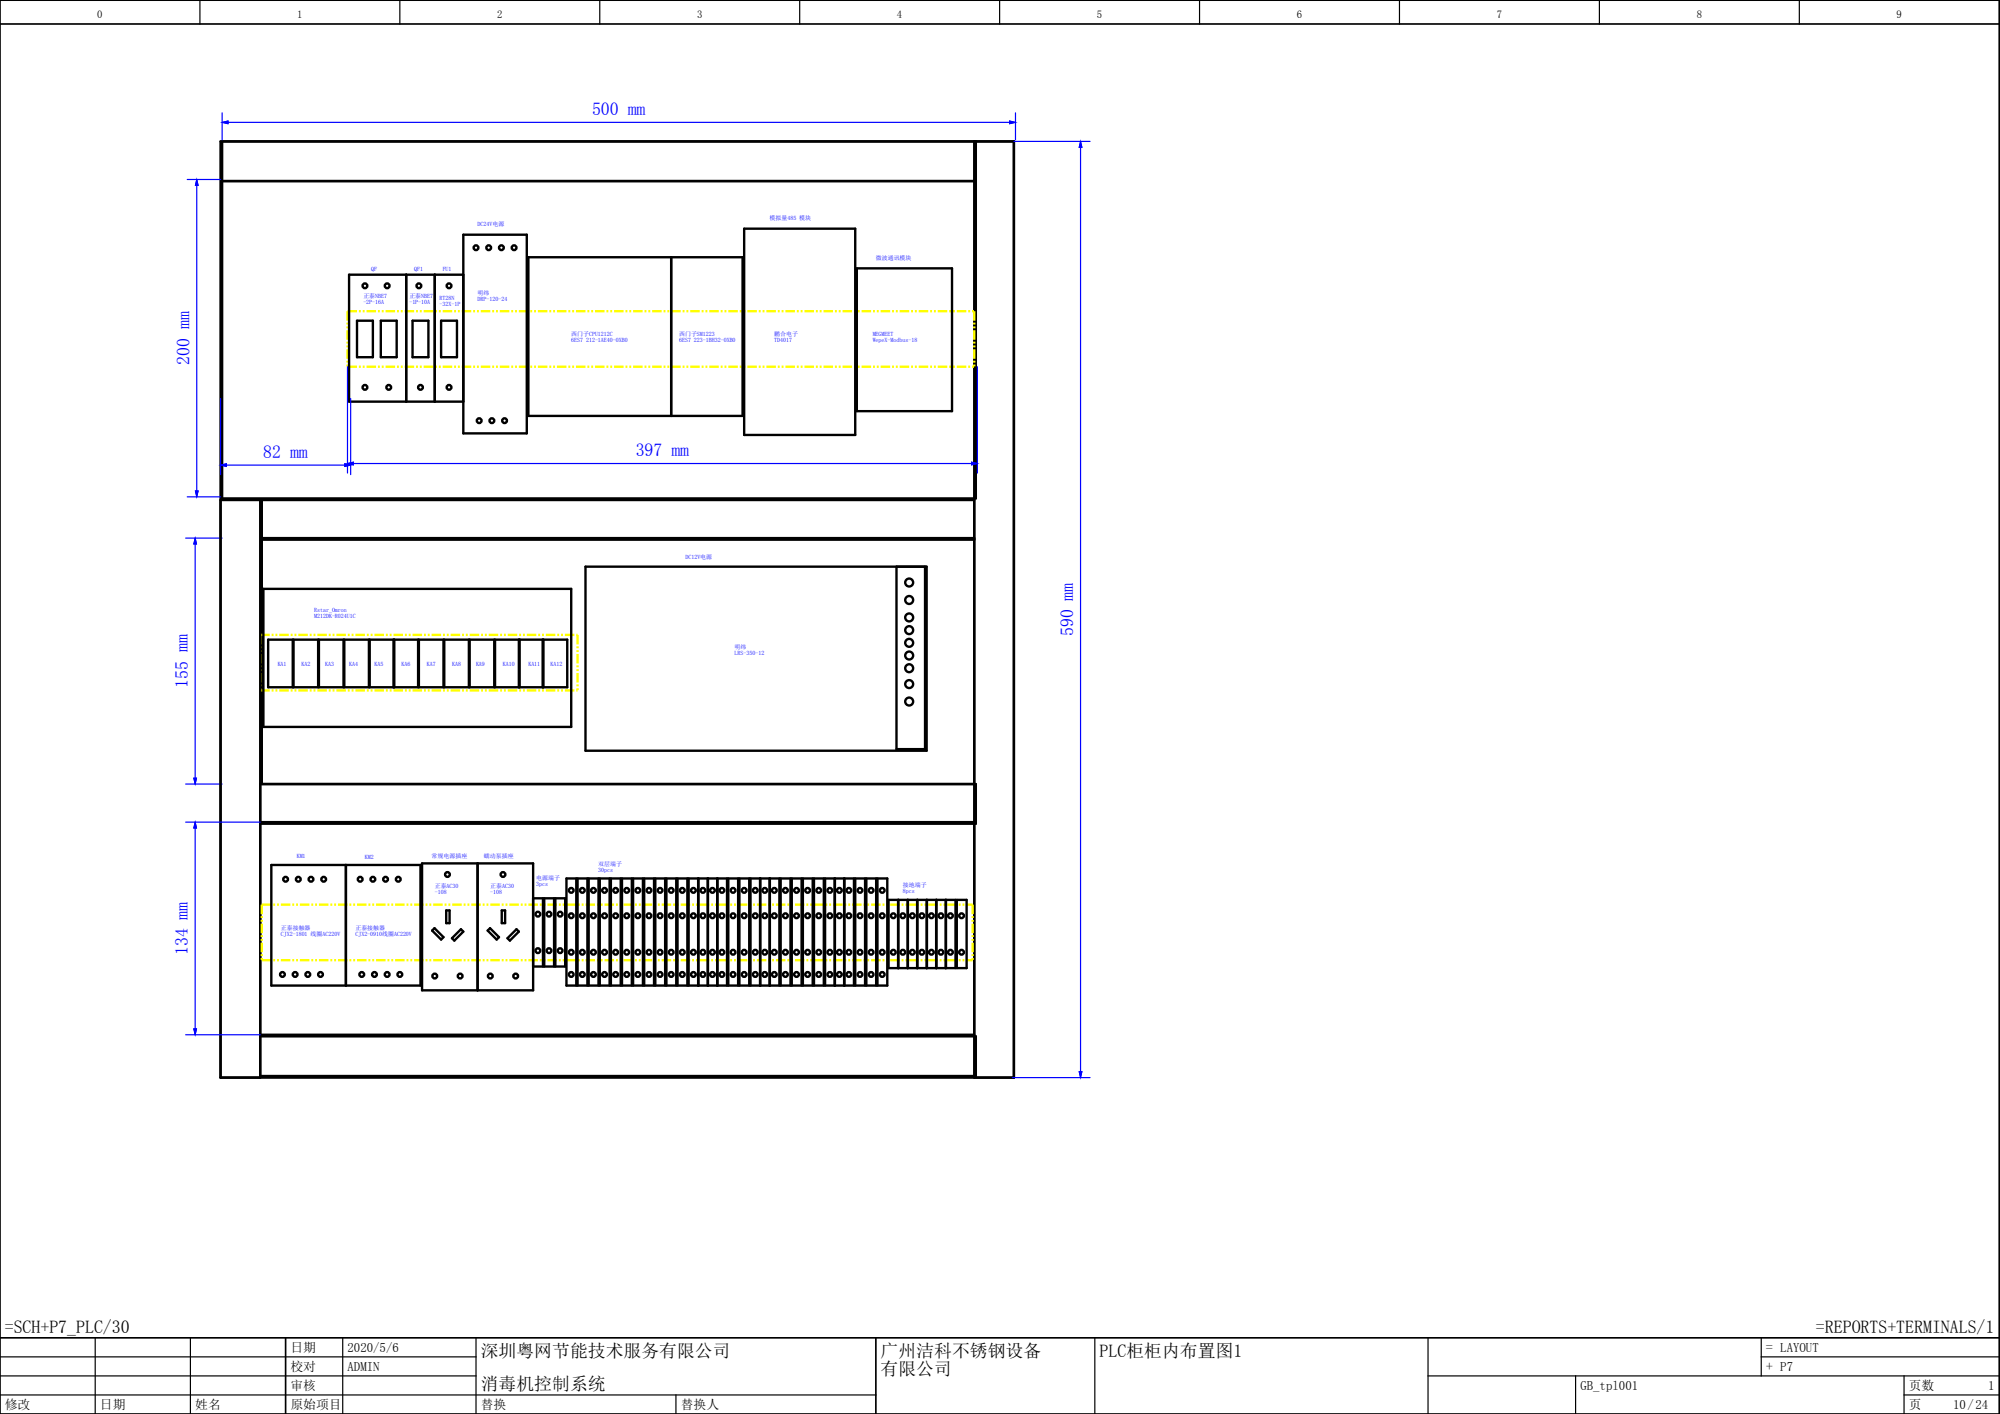
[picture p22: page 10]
=SCH+P7_PLC/30; LAYOUT; ‎PLC柜柜内布置图1; =REPORTS+TERMINALS/1; ‎广州洁科不锈钢设备; Rstar_Omron M212DK-R024U1C; ‎电源端子 3pcs; ‎双层端子 30pcs; ‎接地端子 8pcs; ‎明纬 LRS-350-12; ‎明纬 DRP-120-24; ‎DC24V电源; ‎模拟量485 模块; ‎微波通讯模块; ‎DC12V电源; ‎常规电源插座; ‎蠕动泵插座

‎正泰NBE7 -2P-16A | ‎正泰NBE7 -1P-10A | RT28N -32X-1P

‎西门子CPU1212C 6ES7 212-1AE40-0XB0 | ‎西门子SM1223 6ES7 223-1BH32-0XB0 | ‎鹏合电子 TD4017 | MEGMEET WepeX-Modbus-18

‎正泰AC30 -108 | ‎正泰AC30 -108

‎正泰接触器 ‎CJX2-1801 线圈AC220V | ‎正泰接触器 ‎CJX2-0910线圈AC220V

# ‎端子连接图

F11_001

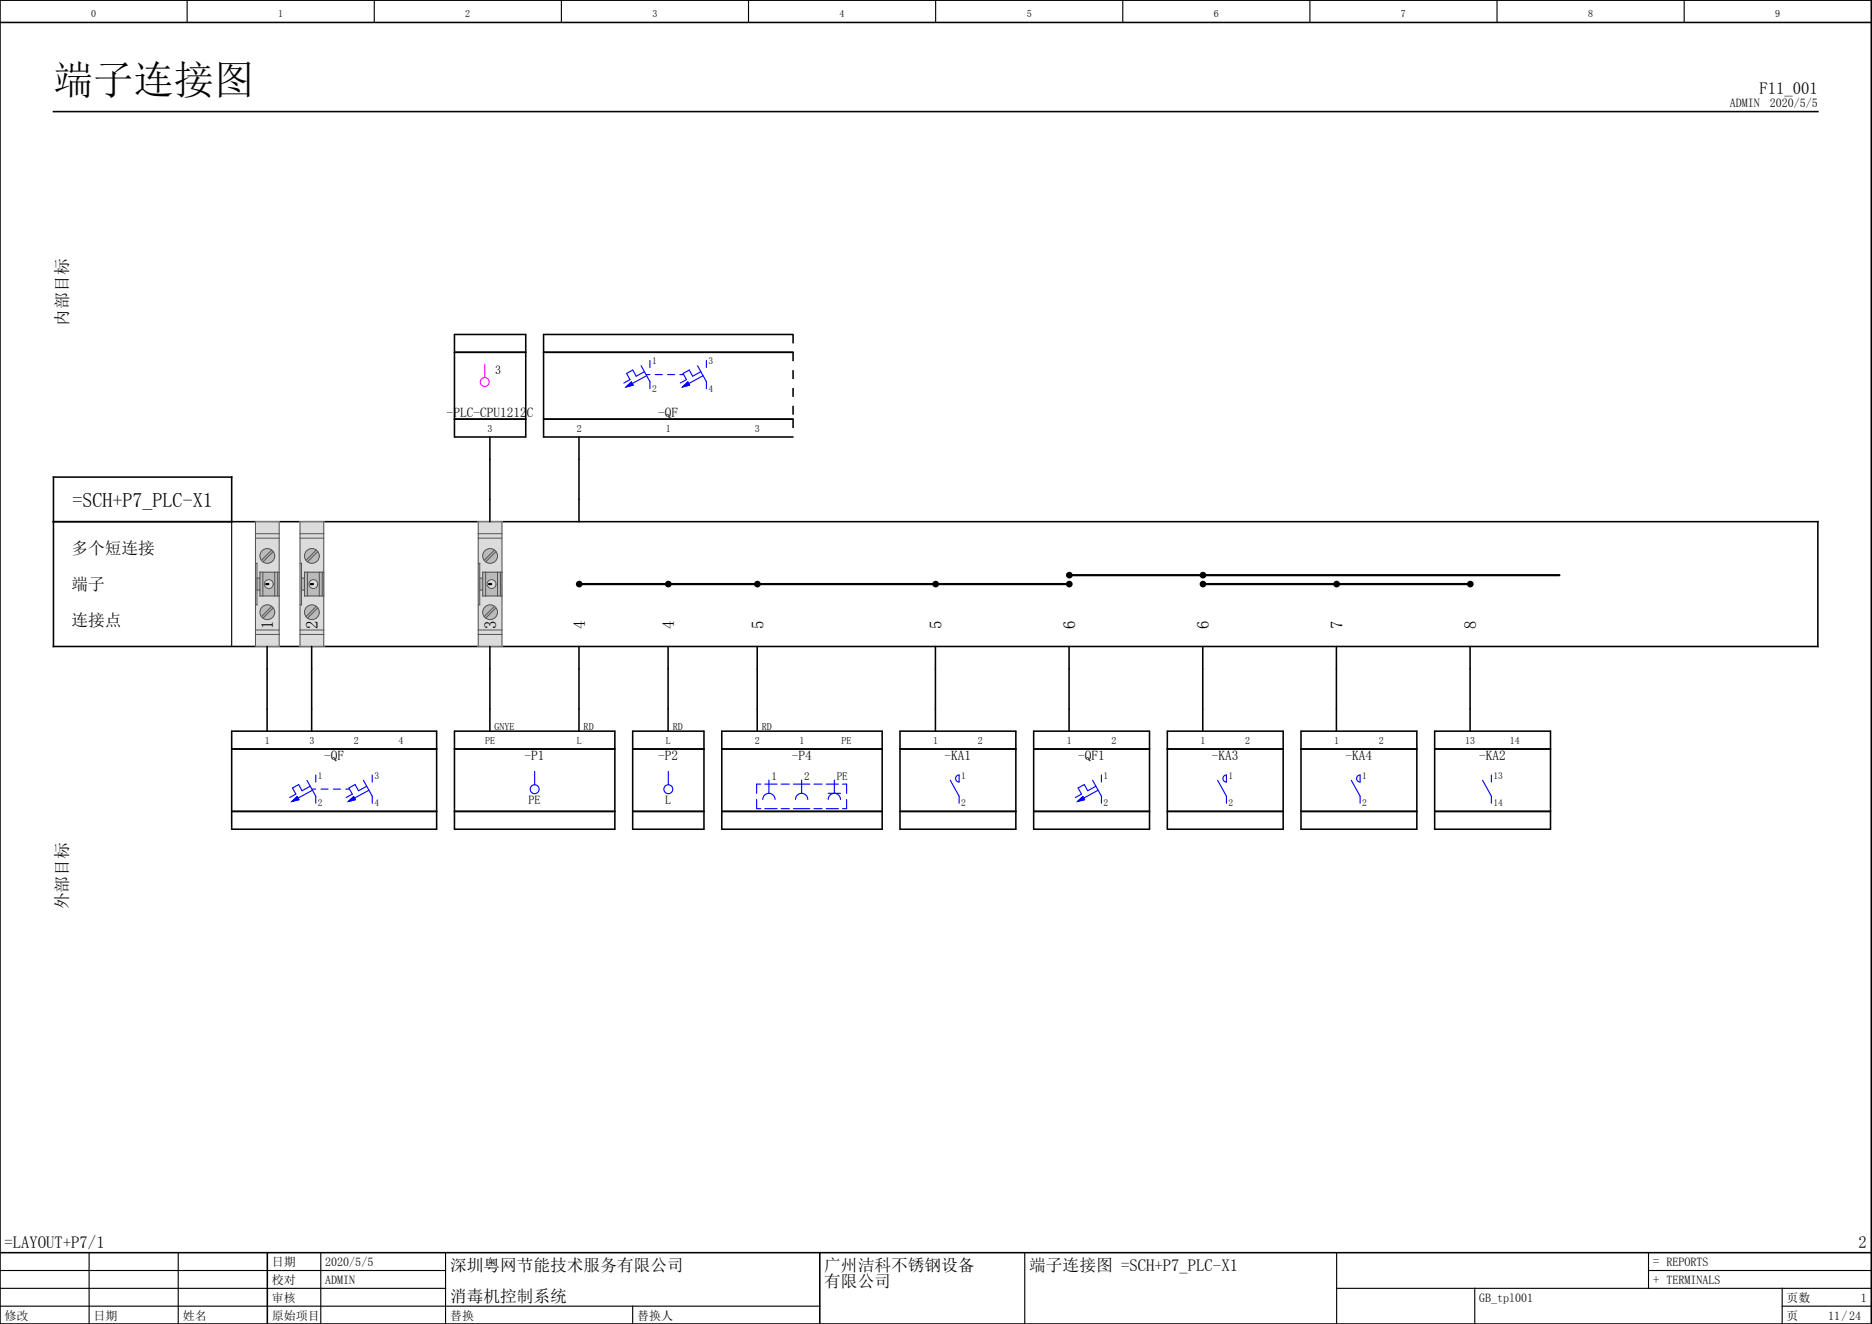
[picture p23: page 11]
=LAYOUT+P7/1; REPORTS; TERMINALS; ‎端子连接图 =SCH+P7_PLC-X1; ‎广州洁科不锈钢设备; ‎内部目标; ‎外部目标; ADMIN 2020/5/5; =SCH+P7_PLC-X1; -PLC-CPU1212C

‎多个短连接 ‎端子 ‎连接点

GNYE | RD | RD | RD

# ‎端子连接图

F11_001

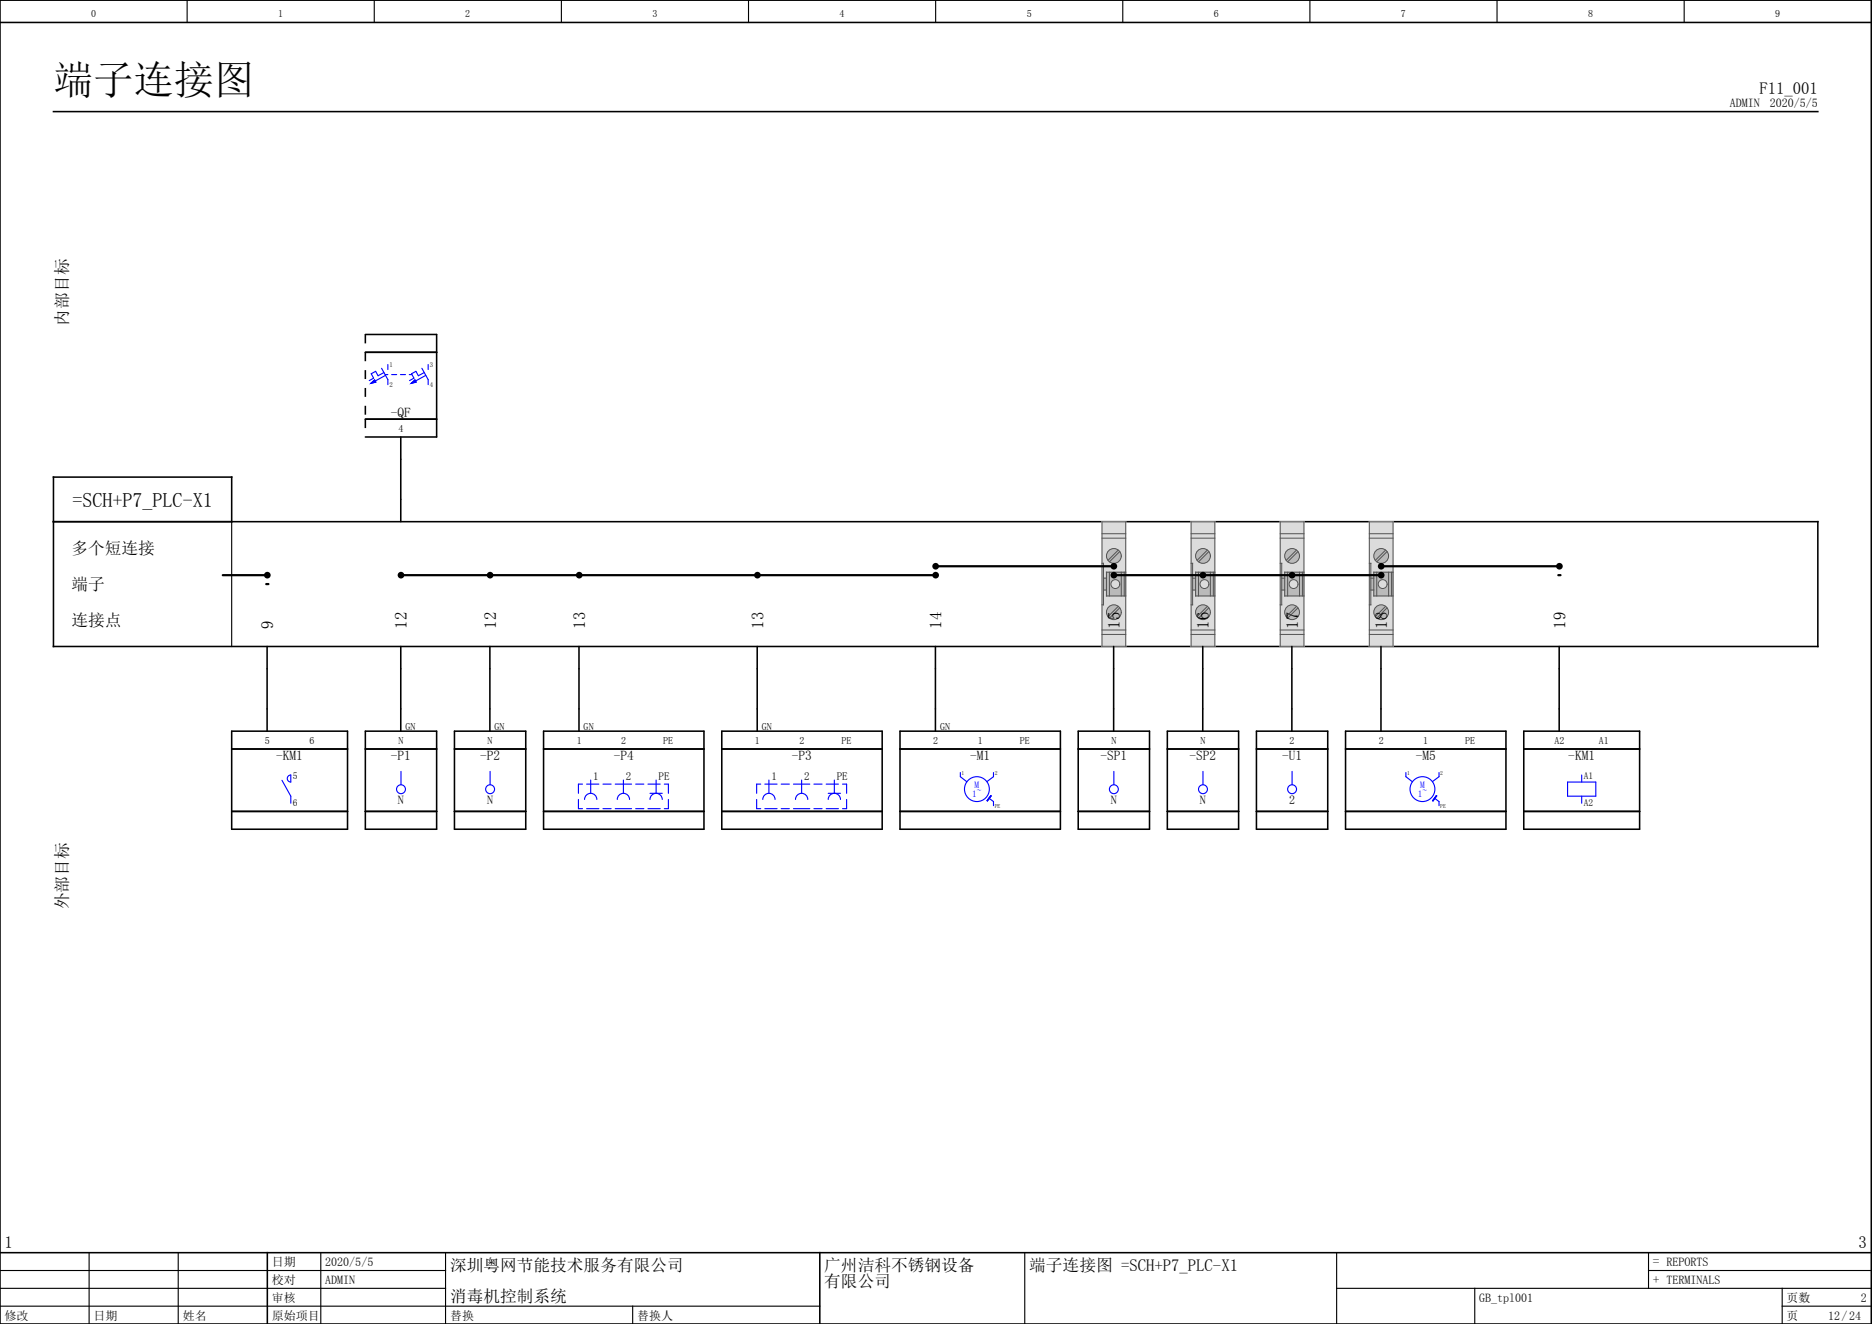
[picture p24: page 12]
‎端子连接图 =SCH+P7_PLC-X1; ‎内部目标; ‎外部目标; ADMIN 2020/5/5; =SCH+P7_PLC-X1

‎多个短连接 ‎端子 ‎连接点

GN¹² | GN¹² | GN¹³ | GN¹³ | GN¹⁴

# ‎端子连接图

F11_001

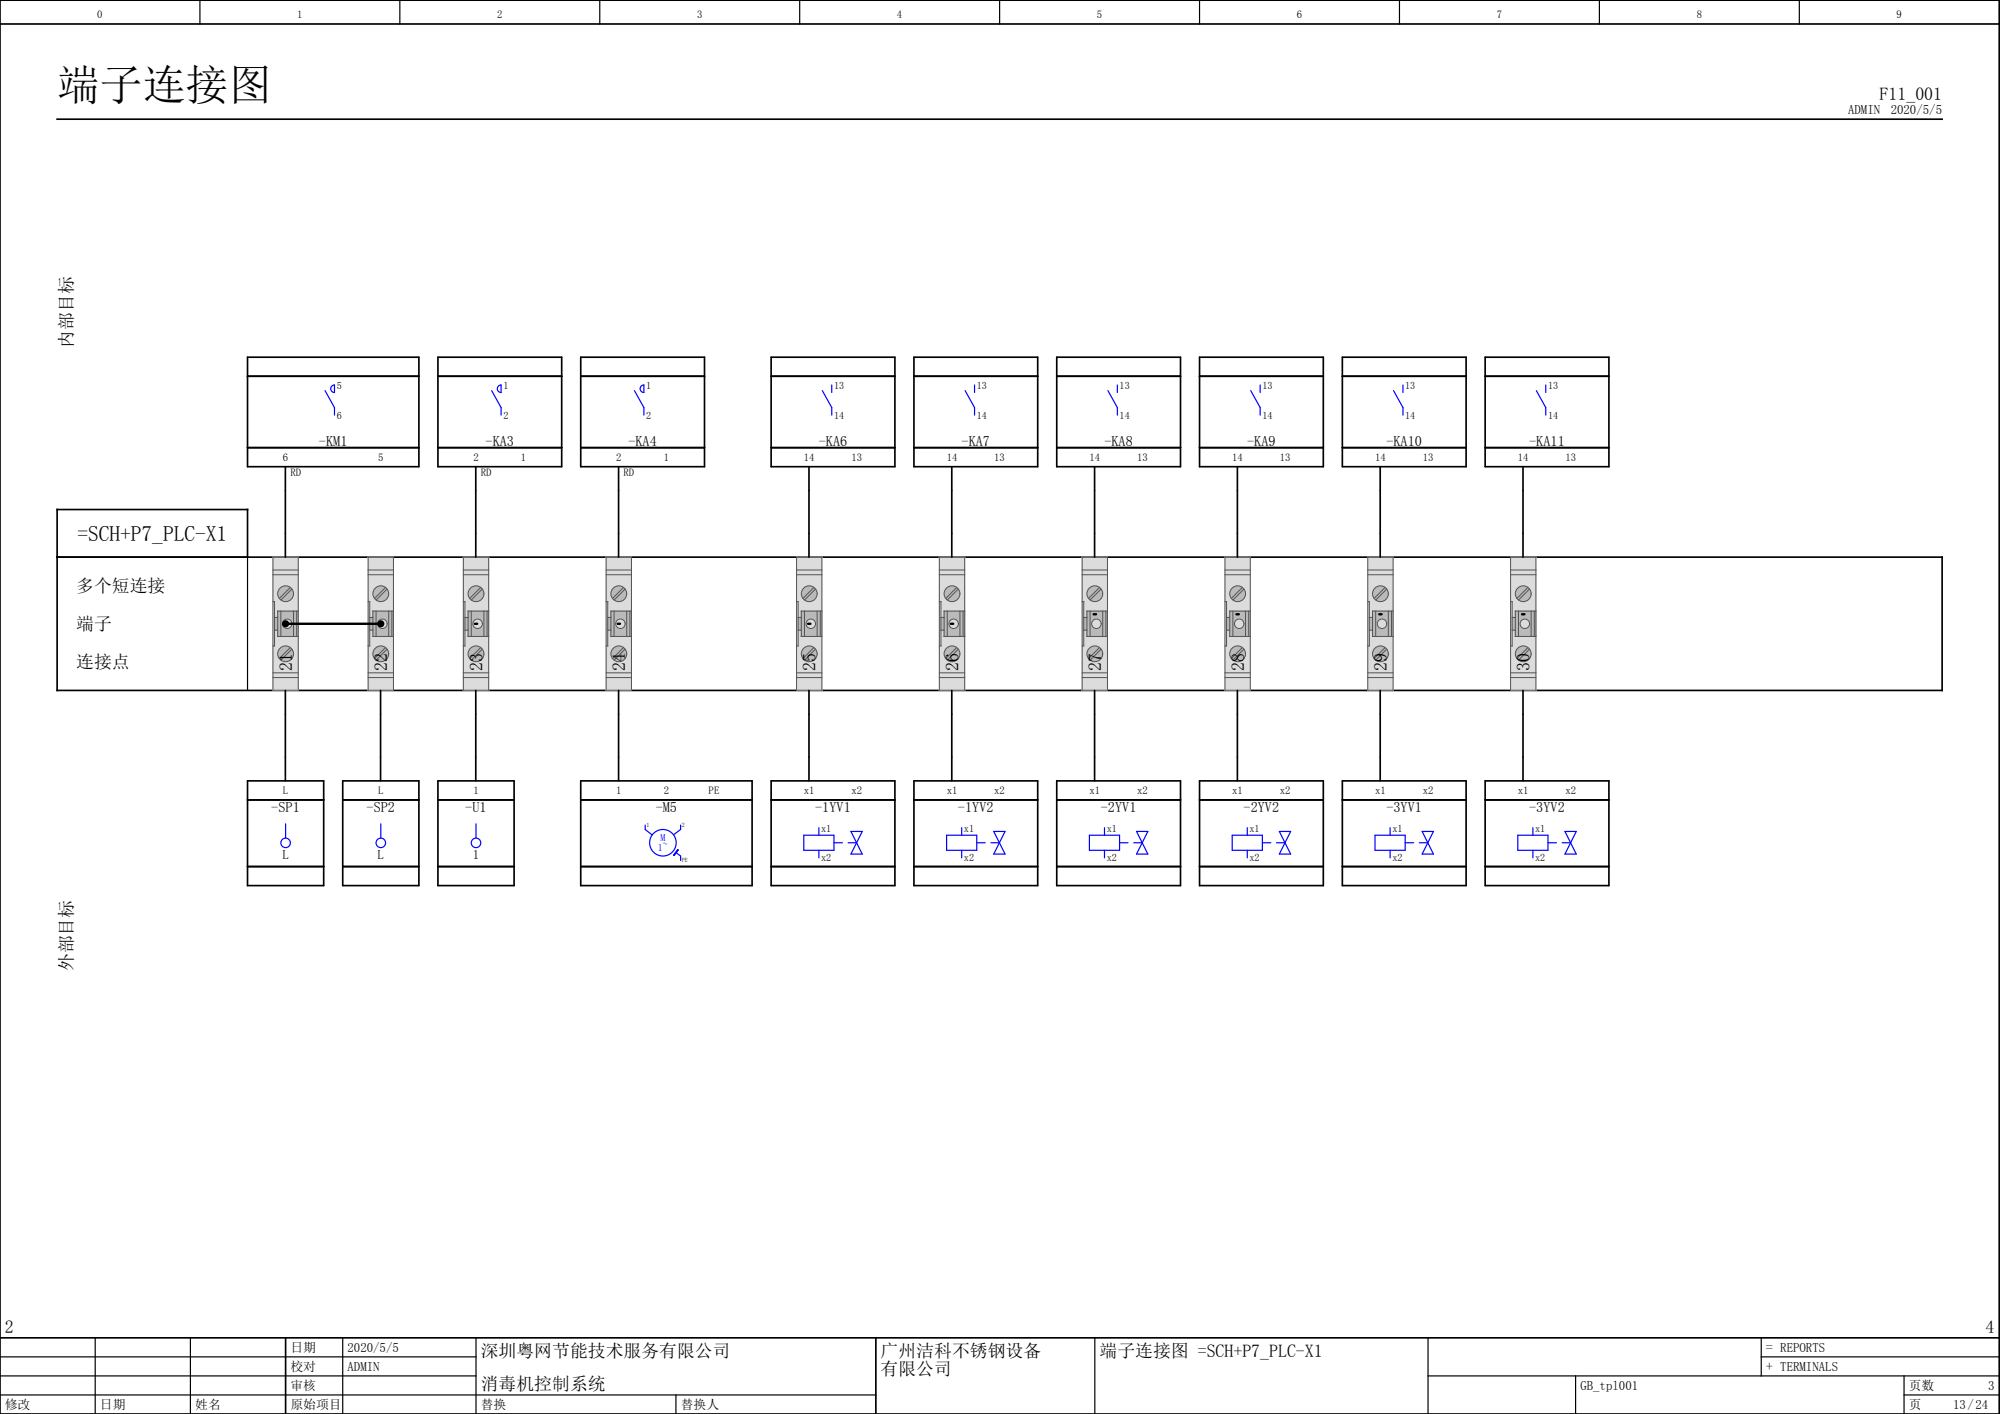
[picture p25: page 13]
‎端子连接图 =SCH+P7_PLC-X1; ‎多个短连接; ‎内部目标; ‎连接点; ‎外部目标; ADMIN 2020/5/5; =SCH+P7_PLC-X1

‎端子连接图 =SCH+P7_PLC-X1; ‎端子连接图; ‎多个短连接; ‎内部目标; ‎连接点; ‎外部目标; ADMIN 2020/5/5; =SCH+P7_PLC-X1

# ‎端子连接图

F11_001

‎端子连接图 =SCH+P7_PLC-X2; ‎多个短连接; ‎内部目标; ‎连接点; ‎外部目标; ADMIN 2020/5/5; =SCH+P7_PLC-X2; -Temperature1; -Pressure1; -PLC-CPU1212C; -Flowmeter1; -E-STOP; 6 -Start; -Flowmeter2; -WepeXModbus

# ‎端子连接图

F11_001

‎端子连接图 =SCH+P7_PLC-X2; ‎多个短连接; ‎内部目标; ‎连接点; ‎外部目标; ADMIN 2020/5/5; GND; =SCH+P7_PLC-X2; -Flowmeter2; -PLC-CPU1212C; -Temperature1; -Pressure1; -Flowmeter1

# ‎端子连接图

F11_001

‎端子连接图 =SCH+P7_PLC-X2; ‎多个短连接; ‎内部目标; ‎连接点; ‎外部目标; ADMIN 2020/5/5; =SCH+P7_PLC-X2; -Temperature1; -Flowmeter2; -PLC-CPU1212C; -Pressure1; -Flowmeter1; GNYE 40

# ‎端子连接图

F11_001

‎端子连接图 =SCH+P7_PLC-X2; ‎内部目标; ‎外部目标; ADMIN 2020/5/5; =SCH+P7_PLC-X2; -E-STOP; -PLC-CPU1212C; -Start

‎多个短连接 ‎端子 ‎连接点

GN⁴³ | GNYE ⁴⁸ | GNYE ⁴⁹
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

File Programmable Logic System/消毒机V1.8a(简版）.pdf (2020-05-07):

| | | | 2020/3/13 | ‎深圳粤网节能技术服务有限公司 ‎消毒机控制系统 | ‎广州洁科不锈钢设备 ‎有限公司 | ‎封页 | = COVER
| | | ‎校对 | ADMIN | | | | +
| | | ‎审核 | | | | | GB_tpl001 | ‎页数
‎修改 | ‎日期 | ‎姓名 | ‎原始项目 | | ‎替换 | ‎替换人 | | | | ‎页
0 | 6 | 7
3 | 8 | 9

## =SCH+P7_PLC/1

# ‎深圳粤网节能技术服务有限公司

# ‎消毒机控制系统电气原理图

# ‎工程编号XXX-YYY-ZZZ

# ‎______年___月

# ‎施工图

X1

X1

=COVER+/1; SCH; P7_PLC; ‎广州洁科不锈钢设备; ‎电柜风扇; ‎明伟DRP-120-24 ‎输出DC24V,5A; ‎电源指示; ‎电源插座; GNYE

POWER SUPPLY AND Main Circuit

24V+

-KM1

SCH; P7_PLC; ‎广州洁科不锈钢设备; WepeX 1600A; ‎微波高压 ‎开关电源; ‎微波源; PIW66 PIW64; GNYE; 10.8 / PIW64; 10.8 / PIW66

POWER SUPPLY AND Main Circuit

L1

N1

SCH; P7_PLC; ‎冰水机 0.75KW; GNYE

POWER SUPPLY AND Main Circuit

24V+

24V-

SCH; P7_PLC; ‎PLC_CPU接线图; ‎微波高压; ‎开关电源; ‎冰水机; ‎氮气阀1; ‎氮气阀2; Buzzer; -PLC-CPU1212C; PIW64; PIW66; -E-STOP; -Start; GNYE

24V+

24V-

SCH; P7_PLC; ‎模拟量模块接线图; Temperature1; Pressure1; Flowmeter2; Flowmeter1; DATA+; DATA-; GND; GNYE

L1

X1

SCH; P7_PLC; ‎中继输出接线图; ‎氮气阀1; ‎氮气阀2; CJX2-1801

24V+

24V-

SCH; P7_PLC; ‎通讯网络; =LAYOUT+P7/1; ‎广州洁科不锈钢设备; CPU-1212C; WEINVIEW; Camera1; Camera2; NO Camera; PORT1; eMT3070B; DATA+; DATA-; GND; -WepeXModbus

500 mm

=SCH+P7_PLC/30; LAYOUT; ‎PLC柜柜内布置图1; =REPORTS+TERMINALS/1; ‎广州洁科不锈钢设备; Rstar_Omron; ‎正泰接触器; ‎CJX2-1801 线圈AC220V; ‎电源端子 3pcs; ‎双层端子 28pcs; ‎接地端子 8pcs

‎正泰NBE7 | ‎正泰NBE7 -1P-10A | RT28N -32X-1P | ‎正泰AC30 -108 | ‎明纬NDR-120-24 -2P-16A

‎西门子CPU1212C 6ES7 212-1AE40-0XB0 | ‎鹏合电子 TD4017 | MEGMEET WepeX-Modbus-18

# ‎端子连接图

F11_001

=LAYOUT+P7/1; REPORTS; TERMINALS; ‎端子连接图 =SCH+P7_PLC-X1; ‎内部目标; ‎外部目标; ADMIN 2020/5/5; =SCH+P7_PLC-X1; -PLC-CPU1212C

‎多个短连接 ‎端子 ‎连接点

GNYE | RD | RD | GN¹²

# ‎端子连接图

F11_001

‎端子连接图 =SCH+P7_PLC-X1; ‎内部目标; ‎外部目标; ADMIN 2020/5/5; =SCH+P7_PLC-X1

‎多个短连接 ‎端子 ‎连接点

GN¹³ | GN¹⁴

# ‎端子连接图

F11_001

‎端子连接图 =SCH+P7_PLC-X1; ‎多个短连接; ‎内部目标; ‎连接点; ‎外部目标; ADMIN 2020/5/5; =SCH+P7_PLC-X1

# ‎端子连接图

F11_001

‎端子连接图 =SCH+P7_PLC-X2; ‎多个短连接; ‎内部目标; ‎连接点; ‎外部目标; ADMIN 2020/5/5; =SCH+P7_PLC-X2; -Temperature1; -Pressure1; -PLC-CPU1212C; -Flowmeter1; -E-STOP; -Start; -Flowmeter2; -WepeXModbus

# ‎端子连接图

F11_001

‎端子连接图 =SCH+P7_PLC-X2; ‎多个短连接; ‎内部目标; ‎连接点; ‎外部目标; ADMIN 2020/5/5; GND; =SCH+P7_PLC-X2; -PLC-CPU1212C; -Temperature1; -Pressure1; -Flowmeter1; -Flowmeter2

# ‎端子连接图

F11_001

‎端子连接图 =SCH+P7_PLC-X2; ‎内部目标; ‎外部目标; ADMIN 2020/5/5; =SCH+P7_PLC-X2; -Temperature1; -Pressure1; -Flowmeter1; -Flowmeter2; -E-STOP; -Start; -PLC-CPU1212C

‎多个短连接 ‎端子 ‎连接点

GNYE ⁴⁸

‎端子连接图 =SCH+P7_PLC-X2; ‎端子连接图; ‎多个短连接; ‎内部目标; ‎连接点; ‎外部目标; ADMIN 2020/5/5; =SCH+P7_PLC-X2; GNYE ⁴⁹

‎功能文本 | | | | | | ‎排 =SCH+P7_PLC-X1 | | | | | | ‎页/列
| | | | | ‎目标代号 | | | | ‎目标代号 ‎电缆型号

‎端子图表 =SCH+P7_PLC-X1; ‎电缆型号; ‎连接点; ‎短连接; ‎电缆名称; ‎端子图表

-QF | 1 | 1 | | | | | /1.0
-QF | 3 | 2 | | | | | /1.0
-P1 | PE | 3 | | -PLC-CPU1212C | 3 | | /1.0
-P1 | L | 4 | | -QF | 2 | | /1.2
-P4 | 2 | 5 | | | | | | /1.6
-QF1 | 1 | 6 | | | | | | /1.8
-KA2 | 1 | 6 | | | | | | /3.1
-KA3 | 1 | 7 | | | | | | | /3.3
-KA1 | 13 | 8 | | | | | | | /20.2
-KM1 | 5 | 9 | | | | | | | /2.2
-P1 | N | 12 | | -QF | 4 | | /1.2
-P4 | 1 | 13 | | | | | | /1.5
-M1 | 2 | 14 | | | | | | /1.8
-SP1 | N | 15 | | | | | | /2.2
-SP2 | N | 16 | | | | | | /2.6
-U1 | 2 | 17 | | | | | | /3.1
-M5 | 2 | 18 | | | | | | /3.4
-KM1 | A2 | 19 | | | | | | /20.2
-SP1 | L | 21 | -KM1 | 6 | | | | /2.2

-SP2 | L | 22 | | | | | | /2.6
-U1 | 1 | 23 | | | -KA2 | 2 | | /3.1
-M5 | 1 | 24 | | | -KA3 | 2 | | /3.3
-1YV1 | x1 | 25 | | | -KA4 | 14 | | /20.5
-1YV2 | x1 | 26 | | | -KA5 | 14 | | /20.5
-U1 | 3 | 48 | | | | | | /3.2
-M5 | PE | 48 | | | | | | /3.4

‎功能文本 | | | | | | | ‎排 =SCH+P7_PLC-X2 | | | | | | ‎页/列
| | | | | | ‎目标代号 | | | | ‎目标代号 ‎电缆型号

‎端子图表 =SCH+P7_PLC-X2; ‎电缆型号; ‎连接点; ‎短连接; ‎电缆名称; ‎端子图表

-MS1 | T1 | 2 | | | | | | | /2.4
-Temperature1 | | 2 | | | | | | | | /12.2
-MS2 | T1 | 3 | | | | | | | | | /2.8
-Pressure1 | | 3 | | | | | | | | | /12.3
-PLC-CPU1212C | 1 | 4 | | | | | | | | | /10.1
-Flowmeter1 | | 4 | | | | | | | | | /12.4
-E-STOP | 13 | 5 | | | | | | | | | /10.3
-TD4017+ | 9 | 5 | | | | | | | | | /12.6
-Start | 13 | 6 | | | | | | | | | /10.4

6 | | | | | -Flowmeter2 | 1 | | | /12.2
7 | | -Flowmeter2 | 1 | | | | | /12.3
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

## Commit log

2020-04-23 Create System Conceptual Drawing 0.0.1.pdf
    系统结构图 v 0.0.1
2020-04-24 Update Camera Initialization Instruction.txt
    注意环境变量和参数命名，还有程序路径。
2020-04-24 Create Camera Initialization Instruction.txt
2020-04-24 Create analog_io - 价格.xls
    BOM成本核算
    [analog_io - 价格.xls]
2020-04-24 Create BF706_Core-BOM - 价格.xls
    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
    [BF706_Core-BOM - 价格.xls]
2020-05-04 Change Device ID & Add Multithreads option
2020-05-07 消毒机组态图
2020-05-11 Add files via upload
    ANALOG I/O MODULE SCHEMATIC DRAWING.
    [adc_420.SchDoc, aio_conn.SchDoc, analog_io.PrjPCB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]
2020-12-06 PLX ref schematic.
2021-05-27 Reference schematic
2021-05-28 Add files via upload
    Reference Schematic
